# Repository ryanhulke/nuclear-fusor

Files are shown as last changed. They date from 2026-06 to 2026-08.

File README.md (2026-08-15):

# Nuclear Fusor
A [nuclear fusor](https://en.wikipedia.org/wiki/Fusor) is an inertial electrostatic confinement device that uses a strong electric field to ionize deuterium gas and accelerate the ions toward the center of a vacuum chamber. This is accomplished by applying a large negative voltage to an inner metal grid (the cathode) relative to the grounded chamber wall (the anode). The chamber is operated at low pressure so that ions can travel significant distances and gain energy from the electric field before colliding with other particles. Near the center of the device, some ions collide with enough kinetic energy that, although they still cannot classically overcome the strong [Coulomb repulsion force](https://en.wikipedia.org/wiki/Coulomb's_law) between their positively charged nuclei, they can occasionally [tunnel](https://en.wikipedia.org/wiki/Quantum_tunnelling) through the Coulomb barrier and may fuse, releasing energy and producing fusion products such as neutrons. These devices are purely experimental; they are highly energy-inefficient and have no commercial future. If you have to ask, "then why would I build one?", you probably shouldn't.

## Project Description
Hardware, firmware, and desktop software for the fusor. The build employs 3 microcontrollers with Bluetooth Low-Energy (BLE). One interfaces with the pressure gauge and streams pressure readings to the control panel, another monitors the high-voltage and current, and the third actuates the gas metering valve for remote pressure control. The desktop app control panel brings the live readouts and valve controls together, with option to stream your phone camera to your computer so you can view the plasma at a safe distance. You can also replay recorded sensor logs and camera footage in the control panel for post-run analysis, in either standard or mobile view.

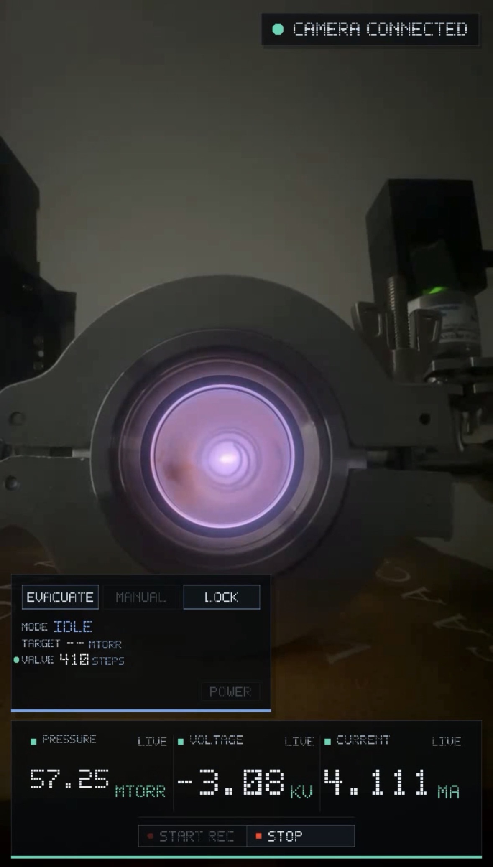
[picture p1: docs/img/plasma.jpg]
Control Panel: Mobile View


## Core Components
- a vacuum pump
  - https://www.amazon.com/Kozyvacu-Dual-Stage-HVAC-Vacuum-Pump/dp/B01N0SYCL4/ref=sr_1_1?sr=8-1
- a vacuum chamber with a view port
  - source these parts from ebay. Use KF or Conflat fittings.
- a high-voltage feedthrough into the chamber
- an inner grid connected to the feedthrough (ex. protein shaker ball)
- a variable power supply capable of at least -20kV at a few mA
- deuterium gas source (or just air for testing)
- MKS 901P pressure gauge
- pressure gauge readout board ([pressure-gauge-readout\hardware](pressure-gauge-readout/hardware))
-  remote-controlled valve ([valve-control/Parts.md](valve-control/Parts.md))
- ammeter/voltmeter readout board ([meter-readouts\hardware](meter-readouts/hardware))
- NEMA 17 Stepper motor (mounted to a needle valve on the deuterium inlet side) and driver
- (optional) ESP32-C6 microcontroller to control the motor
  - a more efficient design would be to incorporate valve control into the meter readout board's PCB

## Repository Layout

| Path | Purpose |
| --- | --- |
| `control-panel/` | Windows OpenGL control panel for pressure, meter, valve control, sensor logging, camera background, and playback. |
| `meter-readouts/` | ESP32-C6 firmware and KiCad hardware for the high-voltage/current readout board. |
| `pressure-gauge-readout/` | ESP32-S3 firmware, desktop utilities, and KiCad hardware for the MKS 901P pressure gauge BLE bridge. |
| `valve-control/` | ESP32-C6 firmware for the stepper-driven valve controller. |
| `docs/` | Project notes and supporting documentation. |

Generated build outputs, local logs, camera media, reference papers, IDE state, and local tool installs are intentionally ignored.

## Getting Started
First, check out the hardware and parts lists to make sure you have what you need. Then, set up the software toolchain(s) for the components you want to build.

| What | Toolchain | Where to start |
| --- | --- | --- |
| **Control panel** — the Windows desktop app | CMake + Visual Studio C++ build tools + OpenCV | [control-panel/README.md](control-panel/README.md) |
| **Firmware** — the three microcontroller boards | PlatformIO | [Firmware](#firmware) below |

Everything below assumes **PowerShell, run from the repo root**. Both toolchains need:

- Windows 10 or newer
- Git (`git --version` to confirm)

### Control Panel

The control panel is a native OpenGL desktop app for the live readouts, valve control, camera, sensor logging, and playback. Its setup has a few steps that are easy to get wrong (installing the C++ build tools, pointing CMake at OpenCV, and adding OpenCV's DLLs to `PATH` before running), so it is documented in one place rather than split across files:

**Follow [control-panel/README.md](control-panel/README.md) top to bottom.** It takes you through installing the build tools, installing OpenCV, building, and running, in order.

### Firmware

The firmware runs on three Seeed XIAO microcontrollers that talk to the control panel over BLE.

**1. Install the toolchain**

- **Python 3** — install from https://www.python.org/ with "Add Python to PATH" checked.
- **PlatformIO Core** — install with pip, then confirm it is on `PATH`:
  ```powershell
  pip install platformio
  pio --version
  ```
- **USB drivers for the Seeed XIAO boards** — usually automatic on Windows 10+. Install a driver manually only if a plugged-in board never shows up.

**2. Build and flash each board**

Each board is built from its own directory. The three commands are the same every time: `pio run` compiles, `pio run -t upload` flashes the board over USB, and `pio device monitor` opens the serial console.

```powershell
cd meter-readouts\firmware
pio run
pio run -t upload
pio device monitor

cd ..\..\pressure-gauge-readout\firmware
pio run
pio run -t upload
pio device monitor

cd ..\..\valve-control\firmware
pio run
pio run -t upload
pio device monitor
```

**3. Reference**

Per-board behavior and BLE payloads are documented in:

- [meter-readouts/firmware/README.md](meter-readouts/firmware/README.md)
- [pressure-gauge-readout/README.md](pressure-gauge-readout/README.md) and [pressure-gauge-readout/firmware/README.md](pressure-gauge-readout/firmware/README.md)
- [valve-control/firmware/README.md](valve-control/firmware/README.md)

## BLE Devices

| Device | BLE name | Role |
| --- | --- | --- |
| Meter readout | `Fusor-Meter` | Publishes filtered high-voltage/current readings as `kv=<n>,ma=<n>,sat=<bits>`. |
| Pressure gauge | `PG-XIAO` | Publishes the MKS 901P pressure readout as text. |
| Valve control | `Fusor-Valve` | Publishes `pos=<n>,open=<n>,mode=<mode>` and accepts movement commands. |

The control panel discovers these devices automatically by BLE name/service UUID.

## Hardware

KiCad projects are included for the readout boards:

- `meter-readouts/hardware/MeterReadouts.kicad_pro`
- `pressure-gauge-readout/hardware/readoutPCB.kicad_pro`

## License
MIT.

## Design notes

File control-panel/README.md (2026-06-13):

# Fusor Control Panel

Native OpenGL control panel for the fusor viewport, pressure gauge, meter readouts, valve control, sensor logging, camera background, and playback.

This guide takes you from nothing to a running app in five steps. Run every command in **PowerShell from the repo root**. You install the build tools once (steps 1–3), build once (step 4), and from then on you only repeat step 5 to run.

> **The OpenCV root.** Everything OpenCV-related is derived from one folder — the directory you extract OpenCV into. This guide calls it `$OpenCVRoot`. Set it once and the build and run steps reuse it, so you never hand-type the long paths twice.

## Step 1 — Visual Studio 2022 Build Tools (C++ compiler)

This provides the MSVC C++ compiler that CMake uses to build the app. Without it, the build fails with "no compiler found."

1. Download the **Build Tools for Visual Studio 2022** from https://visualstudio.microsoft.com/downloads/ (scroll to "Tools for Visual Studio").
2. Run the installer and check the **Desktop development with C++** workload, then install.
3. If you already have Visual Studio Community/Professional with the C++ workload, you can skip this.

## Step 2 — CMake 3.21 or newer

1. Install from https://cmake.org/download/ (choose "Add CMake to the system PATH" during install).
2. Confirm it is available:
   ```powershell
   cmake --version
   ```

## Step 3 — OpenCV

The control panel links against OpenCV at build time and loads its DLLs at run time. CMake does **not** download OpenCV for you, so install it yourself.

1. Download the prebuilt Windows package (`opencv-4.x.x-windows.exe`) from https://github.com/opencv/opencv/releases/latest.
2. Run it — it is a self-extractor — and extract to a folder you will remember, for example `C:\Libraries\opencv`. **That folder is your `$OpenCVRoot`.**
3. Confirm the extract produced an `OpenCVConfig.cmake` and a `bin` folder under it:
   ```powershell
   $OpenCVRoot = "C:\Libraries\opencv"   # the folder you extracted into
   Get-ChildItem $OpenCVRoot -Recurse -Filter OpenCVConfig.cmake | Select-Object FullName
   Get-ChildItem $OpenCVRoot -Recurse -Filter opencv_world*.dll | Select-Object FullName
   ```
   For the prebuilt package these resolve to `$OpenCVRoot\build` (the config) and `$OpenCVRoot\build\x64\vc16\bin` (the DLLs). If you built OpenCV from source instead, point `$OpenCVRoot` at your install folder; the two subpaths may differ (e.g. `...\x64\vc16\lib` and `...\x64\vc16\bin`) — use whatever the commands above print.

## Step 4 — Build the app

This compiles the control panel once. You only repeat it after changing the source.

```powershell
$OpenCVRoot = "C:\Libraries\opencv"   # same folder as step 3
cmake -S control-panel -B control-panel\build -DOpenCV_DIR="$OpenCVRoot\build"
cmake --build control-panel\build --config Release
```

The first configure also downloads GLFW and SimpleBLE via CMake `FetchContent`, so it needs internet access. GLAD is vendored in `tools/glad`.

To start clean, delete the build folder and re-run the two commands above:

```powershell
Remove-Item control-panel\build -Recurse -Force
```

## Step 5 — Run the app

⚠️ **Before launching, add OpenCV's DLL folder to your PATH for this PowerShell session.** This is the step people miss: without it Windows cannot find the OpenCV DLLs and the app fails to start with a missing-DLL error. You must redo this in every new PowerShell window.

```powershell
$OpenCVRoot = "C:\Libraries\opencv"   # same folder as step 3
$env:PATH = "$OpenCVRoot\build\x64\vc16\bin;$env:PATH"
& "control-panel\build\Release\Fusor Control Panel.exe"
```

The app scans for the pressure sensor, meter readout, and valve control boards automatically. If it still reports missing DLLs, you ran the `.exe` in a different PowerShell window than the `$env:PATH` line — run both in the same window.

## Setup at a glance

After the one-time tool installs (steps 1–3), the full build-and-run sequence is:

```powershell
$OpenCVRoot = "C:\Libraries\opencv"   # adjust to where you extracted OpenCV

# Build (repeat only after source changes)
cmake -S control-panel -B control-panel\build -DOpenCV_DIR="$OpenCVRoot\build"
cmake --build control-panel\build --config Release

# Run (repeat every new PowerShell session)
$env:PATH = "$OpenCVRoot\build\x64\vc16\bin;$env:PATH"
& "control-panel\build\Release\Fusor Control Panel.exe"
```

## Configure Camera URL

The control panel reads the camera URL from:

```text
control-panel/config/config.yaml
```

Default local bridge config:

```yaml
camera_url: "rtsp://127.0.0.1:8554/fusor"
```

This URL is the MediaMTX RTSP readout on the laptop. The phone streams to MediaMTX separately.

Command-line `--camera-url` still works as a temporary override:

```powershell
& "control-panel\build\Release\Fusor Control Panel.exe" --camera-url "rtsp://127.0.0.1:8554/fusor"
```

## Local iPhone Camera Setup

If you have a Mac, you can obviously use that instead of the iPhone + MediaMTX setup. But for Windows users, the following setup is recommended.

```text
iPhone Moblin -> SRT over iPhone hotspot -> laptop MediaMTX -> RTSP 127.0.0.1 -> Fusor Control Panel
```

The phone and laptop do not need a router. The laptop connects directly to the iPhone hotspot.

### 1. Start The iPhone Hotspot

On iPhone:

```text
Settings -> Personal Hotspot -> Allow Others to Join
```

Connect the laptop to that hotspot.

Find the laptop's hotspot IP:

```powershell
ipconfig
```

Look under the `Wi-Fi` adapter.

Use the laptop's actual IPv4 address in the Moblin URL.

### 2. Install And Run MediaMTX

Download MediaMTX from:

- https://github.com/bluenviron/mediamtx/releases/latest

Download the Windows amd64 zip, extract it, then run:

```powershell
.\mediamtx.exe
```

Allow it through Windows Firewall on private networks.

Default MediaMTX ports:

```text
SRT ingest: 8890/udp
RTSP read: 8554/tcp
```

Leave the MediaMTX PowerShell window open.

### 3. Configure Moblin

Install Moblin on iPhone:

- https://apps.apple.com/us/app/moblin/id6466745933
- https://github.com/eerimoq/moblin

Create a custom stream:

```text
Protocol: SRT
URL: srt://<LAPTOP_HOTSPOT_IP>:8890
Stream ID: publish:fusor
```

Recommended video settings:

```text
Codec: H.264 / AVC
Resolution: 1280x720
FPS: 30
Bitrate: 2000-3000 kbps
Keyframe interval: 1 second
```

### 4. Run With Camera

With MediaMTX running and Moblin streaming, launch the app exactly as in step 5 (the camera is picked up automatically from `config.yaml`):

```powershell
$OpenCVRoot = "C:\Libraries\opencv"   # same folder as setup
$env:PATH = "$OpenCVRoot\build\x64\vc16\bin;$env:PATH"
& "control-panel\build\Release\Fusor Control Panel.exe"
```

## Controls

```text
Left drag: orbit 3D view
Mouse wheel: zoom 3D view
F: toggle slow 3D rotation
R: start/stop sensor logging
V: show/hide camera background
A/D: jog valve closed/open in manual mode
Esc: quit
```

The valve panel provides `EVACUATE`, `MANUAL`, and `VENT`. `VENT` opens the valve to its reported open limit and is blocked while the meter reports power present.

When the camera is live and visible, the 3D fusor diagram is hidden. If the camera is turned off with `V`, disconnected, or stale, the 3D diagram is shown.

## Sensor Logging

Logging is available when at least one sensor board is connected. Logs are written to:

```text
logs/run_N.log
```

Camera recordings for the same run are written beside the log:

```text
logs/run_N.mp4
logs/run_N.video.tsv
```

The `.video.tsv` file maps video frames to the sensor-log timeline.

Common columns:

```text
elapsed_s    torr    kv    ma    mode    valve_delta    valve_steps    predicted_mtorr    slope_mtorr_s    command_reason    power_present    video_frame_id    video_frames
```

Inactive sensors are logged as empty fields.

## Playback

The playback tool replays a recorded run video with the same control panel HUD over the camera feed:

```powershell
& "control-panel\build\Release\Fusor Playback.exe" 7
```

You can also pass the log path directly:

```powershell
& "control-panel\build\Release\Fusor Playback.exe" "logs\run_7.log" --speed 0.5
```

To hide the valve/control HUD panel during playback:

```powershell
& "control-panel\build\Release\Fusor Playback.exe" 10 --hide-valve-control
```

To rotate playback video 90 degrees clockwise for a vertical view while keeping
the HUD at the bottom of that rotated view:

```powershell
& "control-panel\build\Release\Fusor Playback.exe" 10 --vertical
```

If a vertical run appears upside down, flip the final oriented frame:

```powershell
& "control-panel\build\Release\Fusor Playback.exe" 10 --vertical --flip
```

To export the video with the HUD overlay instead of opening the playback window:

```powershell
& "control-panel\build\Release\Fusor Playback.exe" 10 --vertical --save
```

By default this writes beside the source video using a name like
`run_10_overlay_vertical.mp4`. You can choose the output path and format by
passing a path after `--save`:

```powershell
& "control-panel\build\Release\Fusor Playback.exe" 10 --vertical --flip --save "logs\run_10_overlay_vertical_flip.mp4"
```

Playback keys:

```text
Space: pause/resume
q or Esc: quit
```

## Troubleshooting

- If the phone stream is live but the app does not show video, check the MediaMTX window for a publisher on path `fusor`.
- If the app logs `camera live`, the RTSP path is working.
- The control panel forces OpenCV/FFmpeg to read RTSP over TCP and ignore audio tracks; leaving Moblin audio off is still preferred.
- The phone will not appear in BLE scan output. BLE scanning is only for the pressure and meter boards.
- If console output mentions `hevc`, switch Moblin to H.264/AVC.
- If Moblin cannot connect, check the laptop Wi-Fi IPv4 address and Windows Firewall.
- If delay is high, lower resolution/bitrate, use H.264, turn audio off, and reduce SRT latency.

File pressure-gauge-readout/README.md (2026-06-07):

# Pressure Gauge Readout

BLE bridge, desktop utilities, and hardware files for reading an MKS 901P
pressure transducer from the control panel app.

## Layout

| Path | Purpose |
| --- | --- |
| `firmware/` | PlatformIO firmware for the Seeed XIAO ESP32S3 BLE pressure bridge. |
| `desktop/server.py` | Simple BLE smoke-test listener for the production pressure payload. |
| `desktop/calibrate_901p.py` | Maintenance script for 901P command/calibration workflows. |
| `hardware/` | KiCad PCB project and mechanical files. |
| `docs/901P-Loadlock-Transducer-Manual.pdf` | Local copy of the 901P transducer manual. |

## Firmware

The firmware uses PlatformIO. If PlatformIO is not installed yet:

```powershell
python -m pip install --upgrade platformio
pio --version
```

Build and upload from the firmware directory:

```powershell
cd pressure-gauge-readout\firmware
pio run
pio run -t upload
```

The production firmware advertises as `PG-XIAO`, queries `@253PR4?;FF`, and
publishes the parsed pressure string over BLE. See `firmware/README.md` for the
full BLE UUIDs and payload format.

## BLE Smoke Test

Use `desktop/server.py` when you only need to verify that the board advertises,
connects, and publishes pressure notifications.

Install the Python dependency for the desktop scripts:

```powershell
python -m pip install bleak
```

Run from the repo root:

```powershell
python pressure-gauge-readout\desktop\server.py
```

The script prints each BLE notification as raw text. It is intentionally small
and does not depend on the control panel app.

## Calibration Utility

`desktop/calibrate_901p.py` is kept as a maintenance utility for direct 901P
command/calibration workflows. It is not required for normal control panel operation.

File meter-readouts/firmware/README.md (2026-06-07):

# Meter Readouts Firmware

Firmware for the Fusor meter readout board. The board reads high-voltage and
current sense signals through an ADS1115 and publishes filtered production
readings over USB serial and BLE.

## Requirements

- Python 3
- PlatformIO Core
- Seeed XIAO ESP32-C6
- ADS1115 on I2C address `0x48`

Verify PlatformIO:

```powershell
python -m pip install --upgrade platformio
pio --version
```

## Build And Upload

From this directory, build first:

```powershell
pio run
```

Connect the XIAO over USB, then upload:

```powershell
pio run -t upload
```

Open the serial monitor:

```powershell
pio device monitor
```

Serial monitor speed is `115200`.

PlatformIO reads the board, framework, upload speed, serial speed, and library
dependencies from `platformio.ini`. The first build downloads the ESP32 platform
and libraries, so it needs internet access.

## Initialization

On boot the firmware:

1. Starts USB serial and prints `Starting Fusor Meter`.
2. Initializes I2C on the board's default `SDA` and `SCL` pins at 100 kHz.
3. Looks for the ADS1115 at `0x48`.
4. Configures the ADS1115 for `GAIN_SIXTEEN` and `128 SPS`.
5. Starts BLE advertising as `Fusor-Meter`.

If the ADS1115 is not found, the board still advertises over BLE but reports:

```text
ERR ADS1115
```

It retries ADS1115 initialization every 3 seconds and reports
`INFO ADS1115 ready` after recovery.

Boot-time input zeroing is disabled by default. To enable it, set
`autoZeroAtBoot` to `true` in `src/main.cpp` and boot with both inputs held at
their zero condition.

## Operation

Every 250 ms the firmware reads:

- ADS1115 differential channel `0-1` for the high-voltage divider sense input.
- ADS1115 differential channel `2-3` for the current shunt sense input.

The readings are averaged, converted to `kV` and `mA`, filtered, printed to USB
serial, and sent over the BLE data characteristic when a client is connected.

BLE details:

```text
Device name: Fusor-Meter
Service UUID: 9b3f1001-7f64-4f76-8f6d-8a2f0b6a4c10
Data UUID:    9b3f1002-7f64-4f76-8f6d-8a2f0b6a4c10
```

Payload format:

```text
kv=<filtered kV>,ma=<total mA>,sat=<voltage saturated><current saturated>
```

`sat=10` means the voltage ADC input is saturated and the current ADC input is
not.

Calibration constants are near the top of `src/main.cpp`:

```text
hvResistorOhms
voltageSenseOhms
currentShuntOhms
voltageSign
currentSign
```

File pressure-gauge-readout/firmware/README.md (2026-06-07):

# Pressure Gauge Readout Firmware

Firmware for the MKS 901P pressure gauge BLE bridge. The board reads the gauge
over UART and publishes the current pressure value over BLE for the control panel app
and simple diagnostic tools.

## Requirements

- Python 3
- PlatformIO Core
- Seeed XIAO ESP32S3
- MKS 901P pressure transducer connected to the XIAO hardware UART
- BLE-capable host for the control panel or desktop test scripts

Verify PlatformIO:

```powershell
python -m pip install --upgrade platformio
pio --version
```

## Build And Upload

From this directory, build first:

```powershell
pio run
```

Connect the XIAO over USB, then upload:

```powershell
pio run -t upload
```

Open the serial monitor:

```powershell
pio device monitor
```

Serial monitor speed is `115200`.

PlatformIO reads the board, framework, serial speed, and library dependencies
from `platformio.ini`. The first build downloads the ESP32 platform and
libraries, so it needs internet access.

## Wiring

The firmware uses the XIAO board's labeled serial pins:

| XIAO pin | Connects to |
| --- | --- |
| `RX` / GPIO44 | 901P TX |
| `TX` / GPIO43 | 901P RX |

The 901P serial link is configured for `9600` baud.

## Operation

On boot the firmware:

1. Starts USB serial.
2. Opens the 901P UART.
3. Starts BLE advertising as `PG-XIAO`.
4. Queries the 901P every 200 ms with `@253PR4?;FF`.
5. Publishes the parsed pressure value over BLE.

BLE details:

```text
Device name: PG-XIAO
Service UUID: 9b3f0001-7f64-4f76-8f6d-8a2f0b6a4c10
Data UUID:    9b3f0002-7f64-4f76-8f6d-8a2f0b6a4c10
```

Normal payload format:

```text
<pressure> Torr
```

Error payloads:

```text
ERR parse
ERR timeout
```

`ERR parse` means the gauge returned data that did not match the expected 901P
ACK format. `ERR timeout` means no complete `;FF`-terminated response arrived
before the read timeout.

## Desktop BLE Test Script

`pressure-gauge-readout/desktop/server.py` is a lightweight BLE smoke test. It
scans for the pressure gauge bridge, connects, subscribes to notifications, and
prints raw payloads.

Install the Python dependency:

```powershell
python -m pip install bleak
```

Run it from the repo root:

```powershell
python pressure-gauge-readout\desktop\server.py
```

This script is useful for checking BLE advertisement, connection, and payload
format without launching the full control panel.

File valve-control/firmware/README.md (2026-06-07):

# Fusor Valve Stepper Controller

Firmware for digitally controlling the fusor gas metering valve with a Seeed XIAO ESP32-C6, TB6600 stepper driver, and NEMA 17 stepper motor.

The controller tracks valve position in step counts, saves position and calibration values to flash, exposes BLE control for the control panel app, and keeps a USB serial console available for calibration and maintenance.

## Hardware

- Seeed XIAO ESP32-C6
- TB6600 stepper motor driver
- NEMA 17 stepper motor
- 12 V DC power supply, 3-5 A recommended
- Metering valve with motor/coupler mount

Stepper settings:

- Microstepping: 16 microsteps
- Steps per revolution: 3200
- TB6600 current limit: 2 A

## Software Requirements

- Python 3
- PlatformIO Core

Verify PlatformIO:

```powershell
pip install platformio
pio --version
```

PlatformIO reads the board, framework, upload speed, serial speed, partition
layout, and library dependencies from `platformio.ini`. The first build
downloads the ESP32 platform and libraries, so it needs internet access.

## Build, Upload, And Serial

From this directory, build first:

```powershell
pio run
```

Connect the XIAO over USB, then upload:

```powershell
pio run -t upload
```

Open the USB serial console:

```powershell
pio device monitor
```

Serial monitor speed is `115200`.

The serial console is not only for first-time setup. It remains available during normal operation. If the control panel is connected over BLE, you can still plug in USB, open the PlatformIO serial monitor, jog the valve, print status, restore limits, or recalibrate.

## Normal Operation

In normal operation:

1. Power the valve controller.
2. Start the control panel app.
3. The control panel connects over BLE to `Fusor-Valve`.
4. The firmware reports status once per second and after every move.
5. The control panel sends text commands over BLE, such as `MOVETO`, `MOVE`, `CLOSE`, and `OPEN`.

The firmware also accepts the same text commands from USB serial. On USB, type `:` first, then the command, then Enter.

Example:

```text
:STATUS
:MOVETO 1200
:CLOSE
```

## RUN vs CALIBRATE

The firmware has two persisted modes:

- `RUN`: normal clamped operation. Absolute and relative moves are clamped to `[0, openLimitSteps]`.
- `CALIBRATE`: unclamped operation. Use this when finding or correcting the physical closed and open references.

Switch modes from USB serial or BLE:

```text
:MODE RUN
:MODE CALIBRATE
```

Calibration is not a separate firmware or special boot mode. It is always available through USB serial. For normal control-panel-driven use, leave the controller in `RUN`. When you need to recalibrate, connect USB, open `pio device monitor`, switch to `CALIBRATE`, make corrections, then switch back to `RUN`.

Position is saved after every completed move in both modes. The open limit and mode are also saved when changed.

## First-Time Calibration

Use USB serial for calibration.

1. Upload the firmware and open `pio device monitor`.
2. Switch to calibration mode:

   ```text
   :MODE CALIBRATE
   ```

3. Start the vacuum pump.
4. Jog toward closed with `a` or the left arrow while watching pressure.
5. When pressure stops dropping, treat that as the closed reference and press `z`.
6. Jog toward open with `d` or the right arrow.
7. When the valve is open far enough for your system, press `m` to save the open limit.
8. Press `p` or type `:STATUS` and confirm `pos`, `open`, and `mode`.
9. Switch back to clamped normal operation:

   ```text
   :MODE RUN
   ```

After this, the control panel can use the reported `open=<n>` value for Vent and manual jogs remain clamped inside the saved range.

## Recalibration During Normal Use

You can recalibrate without reflashing and without changing how the control panel connects.

1. Leave the controller powered.
2. Connect USB.
3. Open:

   ```text
   pio device monitor
   ```

4. Switch to `CALIBRATE` if you need unclamped jogs:

   ```text
   :MODE CALIBRATE
   ```

5. Correct the position or limit:

   ```text
   :SETPOS <n>
   :SETOPEN <n>
   ```

   Or jog to the references and use `z` / `m`.

6. Switch back to `RUN`:

   ```text
   :MODE RUN
   ```

BLE remains active while doing this. Be careful not to command motion from the control panel and the serial console at the same time.

## Restoring Calibration Without Jogging

If flash was wiped or you already know the calibration values, restore them directly:

```text
:SETOPEN 12800
:SETPOS 7800
:MODE RUN
```

`SETOPEN` requires a positive value. `SETPOS` is clamped if the firmware is currently in `RUN`; switch to `CALIBRATE` first if you need to assert a position outside the current limit.

## USB Serial Commands

Single-character commands execute immediately:

| Key | Effect |
| --- | --- |
| `a` / left arrow | Jog closed |
| `d` / right arrow | Jog open |
| `c` | Move to closed position `0` |
| `o` | Move to the saved open limit |
| `p` | Print status and publish BLE status |
| `z` | Set current position as zero |
| `m` | Mark current position as open limit |
| `[` / `]` | Smaller / bigger jog size |
| `?` | Print help |

Text commands use `:` plus Enter:

```text
:MODE CALIBRATE
:MODE RUN
:SETOPEN <n>
:SETPOS <n>
:MOVETO <n>
:MOVE <delta>
:CLOSE
:OPEN
:STATUS
```

Backspace edits the line buffer. Escape cancels the buffered command.

## BLE Interface

BLE is always active in both `RUN` and `CALIBRATE`.

```text
Device name:    Fusor-Valve
Service UUID:   9b3f2001-7f64-4f76-8f6d-8a2f0b6a4c10
Status UUID:    9b3f2002-7f64-4f76-8f6d-8a2f0b6a4c10  (read + notify)
Command UUID:   9b3f2003-7f64-4f76-8f6d-8a2f0b6a4c10  (write)
```

Status payload:

```text
pos=<n>,open=<n>,mode=<CALIBRATE|RUN>
```

The status characteristic is updated after every move and once per second as a heartbeat.

The command characteristic accepts the text commands listed above without the leading `:`.

Examples:

```text
STATUS
MOVETO 1200
OPEN
CLOSE
MODE RUN
```

## Position Tracking And Limits

The firmware stores:

- current position: `pos`
- open limit: `open`
- mode: `RUN` or `CALIBRATE`

Position is saved after every completed move. With the partition layout pinned in `platformio.ini`, normal firmware uploads preserve NVS, so calibration should survive firmware updates.

Position can still drift from the physical valve if:

- the motor skips steps,
- the coupler slips,
- the valve is turned by hand while the controller is powered off,
- power is lost during a move.

After any of those, reconnect USB and resync with `:SETPOS <n>`, or jog to a known closed reference and press `z`.

## Notes

- In `RUN`, moves are clamped to `[0, openLimitSteps]`.
- In `CALIBRATE`, moves are intentionally unclamped.
- `OPEN` requires `openLimitSteps > 0`; otherwise it leaves the valve in place and republishes status.
- `MOVETO` and `MOVE` are also clamped in `RUN`.
- The stepper driver is enabled automatically while moving.

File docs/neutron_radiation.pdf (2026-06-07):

## Neutron Radiation From IEC Fusion Reactor

Ryan Hulke

May 20, 2026

Assume isotropic emission:
ϕ(r) = Y
4πr²
| Where Y is the neutron emission rate in neutrons/s and r is distance from the source.
| Assume worst conditions:
Y = 1,000,000 neutrons/s, | r = 1 m
| My fusor is far less capable, and I will be farther than 1 m away.
| The neutron flux is:
ϕ =

1,000,000
4π

n
s · m²

Need a conversion factor from neutrons to Sieverts. Sieverts measure health risk from ionizing radiation while accounting for radiation type and tissue weighting.

| Use Table A.41 from ICRP Publication 116, page 199.
| Source: https://journals.sagepub.com/doi/10.1016/S0146-6453%2896%2990010-X

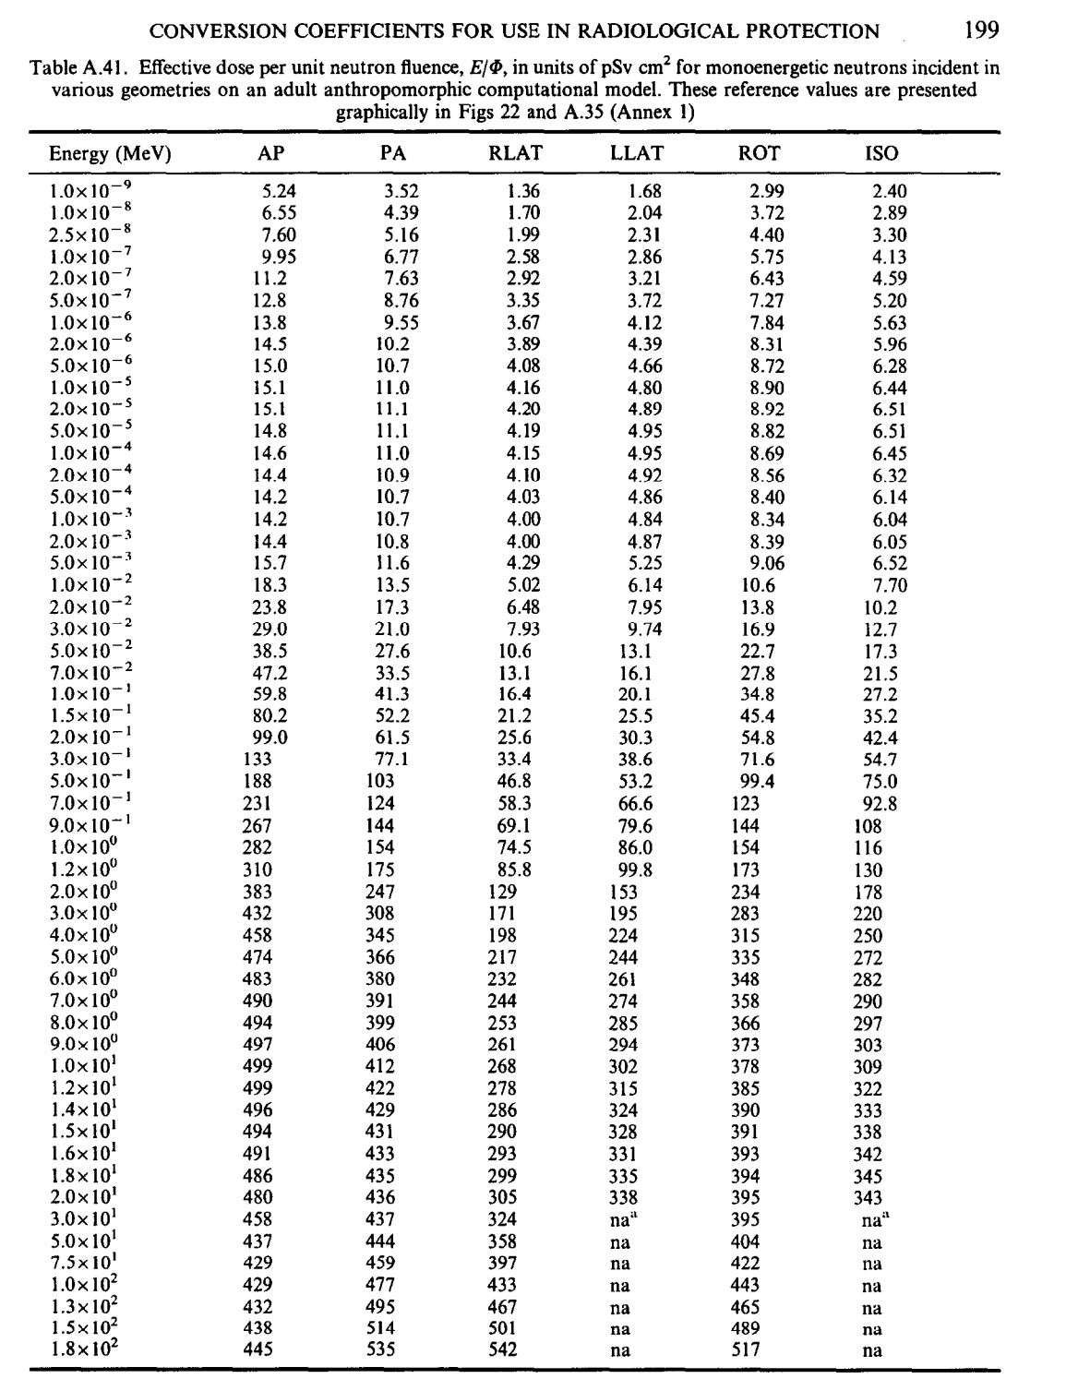
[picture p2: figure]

Effective dose per unit neutron fluence, E/Φ, from ICRP Publication 116 Table A.41.

| The AP column means anterior-to-posterior, which is what you want if a person is facing the radiation source.
| From the table: 2.0 MeV : 383 pSv cm² /neutron 3.0 MeV : 432 pSv cm² /neutron

| D-D fusor neutrons are 2.45 MeV, so interpolate:
| h ≈ 383 + 0.45(432 − 383)
| h ≈ 405 pSv cm² /neutron
| Convert units:
| 405 pSv cm² /neutron = 405 × 10⁻¹² Sv × 10⁻⁴ m² /neutron
| h ≈ 4.05 × 10⁻¹⁴ Sv m² /neutron
| So we use the scaling factor:
| h ≈ 4 × 10⁻¹⁴ Sv m² /neutron
| Plug back in: E˙ ≈ 1,000,000 4π n s · m² · 4 × 10⁻¹⁴ Sv m² n
| Simplify: E˙ ≈ 1,000,000 4π · 4 × 10⁻¹⁴ Sv s E˙ ≈ 3.18 × 10⁻⁹ Sv/s
| E˙ ≈ 3.18 nSv/s
| Scale to hours: E˙ ≈ 3.18 nSv/s · 3600 s/hr
| E˙ ≈ 11.5 µSv/hr
| For context, the NRC public-dose limit for licensed operations is 1 mSv/yr and the unrestricted- area external dose-rate limit is 20 µSv/hr.
| NRC source: https://www.law.cornell.edu/cfr/text/10/20.1301
| Therefore, even a relatively high-yield homemade fusor at 10⁶ neutrons/s gives a neutron dose rate below the NRC unrestricted-area hourly dose-rate limit at 1 m away.
| In fact, natural background radiation is about 0.3 µSv/hr, per the CDC. (https://www.cdc.gov/radiation-health/about/how-to-measure-radiation.html)
| So for every hour you operate a high-powered fusor from 1 m away, you are exposed to about 38 hours of natural background radiation. Nothing.
| This also scales linearly with neutrons/s. So if we assume a more reasonable estimate of 50,000 neutrons/s for my fusor instead of 1,000,000 neutrons/s, exposure drops by a factor of 20: E˙ ≈
| 11.5
| 20 µSv/hr
| E˙ ≈ 0.575 µSv/hr
| when standing 1 m away.

| Distance scales as 1/r² , so going from 1 m to 3 m reduces exposure by a factor of:
| 3 2 = 9
| Therefore: E˙ 3m =
| 0.575
| 9 µSv/hr
| E˙ 3m ≈ 0.064 µSv/hr when standing 3 m away at 50,000 neutrons/s.
| This is the most reasonable estimate for actual operational neutron exposure from my fusor.
| Conclusion: Neutron radiation from my fusor is negligible past 1 m away from the fusor. Just don’t hug it at peak operation.

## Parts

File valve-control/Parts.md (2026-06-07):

# Parts List
- 1x KF16 Vacuum Flow Regulating Valve Metering Controller Needle Valve
- 1x NEMA 17 Stepper Motor
- 1x TB6600 Driver
- 1x XIAO ESP32C6 Microcontroller
- 1x Power Supply (12V/3A)
- 1x 5mm to 6mm Shaft Coupler
- 1x 30mm Inner-width Square U-bolt
- 1x 42mm Stepper Motor Mounting Bracket
- 100x65mm Aluminum Sheet
- 1x Perfboard
- 11x wires
- 1x 3 Double-A Battery Holder
- 3x Double-A Batteries

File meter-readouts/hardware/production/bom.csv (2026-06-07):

Designator | Footprint | Quantity | Value | LCSC Part #
C1, C2, C3, C4 | 0805 | 4 | 100 nF
C5 | 0805 | 1 | 10 uF
D1, D2, D3, D4, D5 | D_SOD-123 | 5 | D_Schottky
R1, R2, R4, R5 | 0805 | 4 | 47 kOhm
R3 | 0805 | 1 | 1 kOhm
R7, R8 | 0805 | 2 | 4.7 kOhm
U1 | TSSOP-10_3x3mm_P0.5mm | 1 | ADS1115IDGS

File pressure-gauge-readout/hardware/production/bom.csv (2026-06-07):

Designator | Footprint | Quantity | Value | LCSC Part #
C1, C10, C11, C12, C4, C6, C8, C9 | 0603 | 8 | 100nF
C2, C3, C5, CR1 | 0603 | 4 | 10uF
D1, D2 | D_SOD-123 | 2 | D_Schottky
F1 | 1812 | 1 | Polyfuse
U1 | SOIC-16_3.9x9.9mm_P1.27mm | 1 | MAX3232

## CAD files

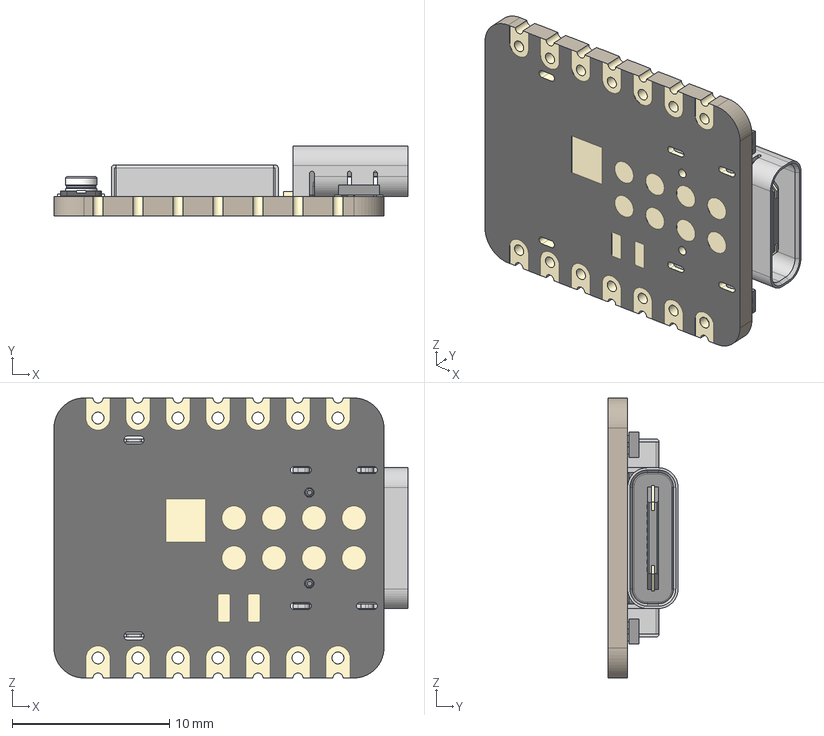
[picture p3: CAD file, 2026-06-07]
meter-readouts/hardware/3dmodels/XIAO-ESP32S3 v2.step
22.5 x 4.46 x 17.8 mm
BOSS-EXTRUDE14_8_
BOSS-EXTRUDE7_4_
BOSS-EXTRUDE7_3_
BOSS-EXTRUDE14_4_
BOSS-EXTRUDE14_2_
BOSS-EXTRUDE14_11_
BOSS-EXTRUDE7_7_
BOSS-EXTRUDE14_9_
BOSS-EXTRUDE14_3_
BOSS-EXTRUDE14_7_
MIRROR2
BOSS-EXTRUDE14_5_
BOSS-EXTRUDE14_12_
BOSS-EXTRUDE7_8_
BOSS-EXTRUDE7_1_
BOSS-EXTRUDE14_10_
BOSS-EXTRUDE7_9_
BOSS-EXTRUDE14_6_
BOSS-EXTRUDE14_1_
BOSS-EXTRUDE7_6_
BOSS-EXTRUDE7_2_
CUT-EXTRUDE5
BOSS-EXTRUDE7_5_
Shield
Pins x 2
U.FL-R-SMT-1_10_ v1

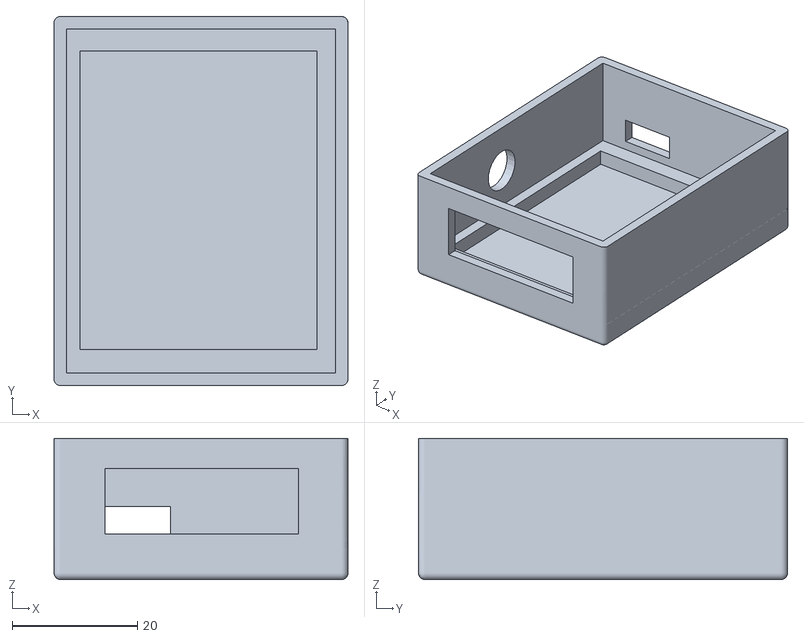
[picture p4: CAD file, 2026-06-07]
pressure-gauge-readout/hardware/3dmodels/enclosure-bottom.stl
46.9 x 58.9 x 22.5

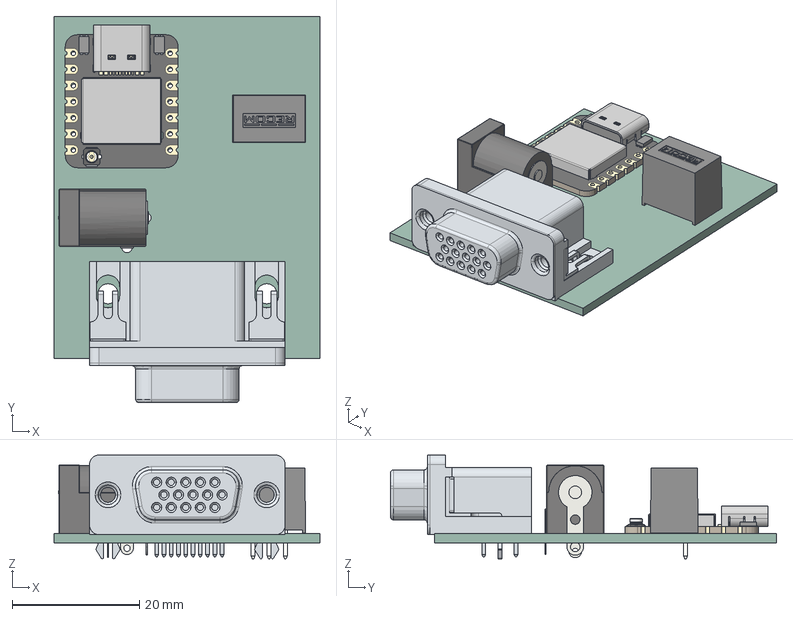
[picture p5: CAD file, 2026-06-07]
pressure-gauge-readout/hardware/readoutPCB.step
41.9 x 60.8 x 16.4 mm
K66X_HT__E15S_N_rA5
BarrelJack_Horizontal
R-78K-1.0_3D_20230223
BOSS-EXTRUDE14_8_
BOSS-EXTRUDE7_4_
BOSS-EXTRUDE7_3_
BOSS-EXTRUDE14_4_
BOSS-EXTRUDE14_2_
BOSS-EXTRUDE14_11_
BOSS-EXTRUDE7_7_
BOSS-EXTRUDE14_9_
BOSS-EXTRUDE14_3_
BOSS-EXTRUDE14_7_
MIRROR2
BOSS-EXTRUDE14_5_
BOSS-EXTRUDE14_12_
BOSS-EXTRUDE7_8_
BOSS-EXTRUDE7_1_
BOSS-EXTRUDE14_10_
BOSS-EXTRUDE7_9_
BOSS-EXTRUDE14_6_
BOSS-EXTRUDE14_1_
BOSS-EXTRUDE7_6_
BOSS-EXTRUDE7_2_
CUT-EXTRUDE5
BOSS-EXTRUDE7_5_
Shield
Pins x 2
U.FL-R-SMT-1_10_ v1
readoutPCB_PCB

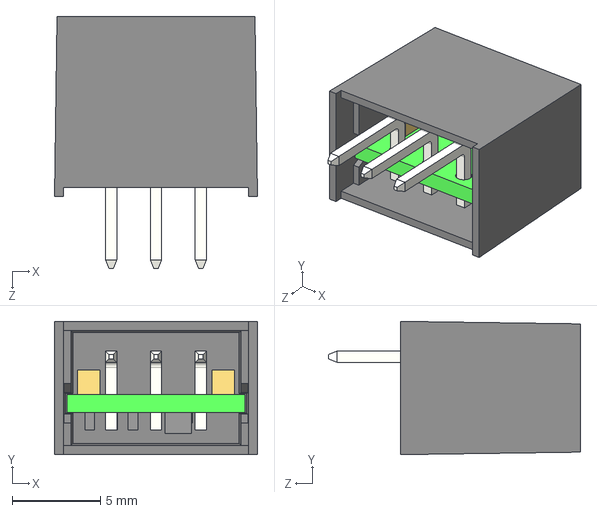
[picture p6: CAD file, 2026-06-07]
pressure-gauge-readout/hardware/3dmodels/R-78K5.0-1.0.step
11.5 x 7.55 x 14.3 mm

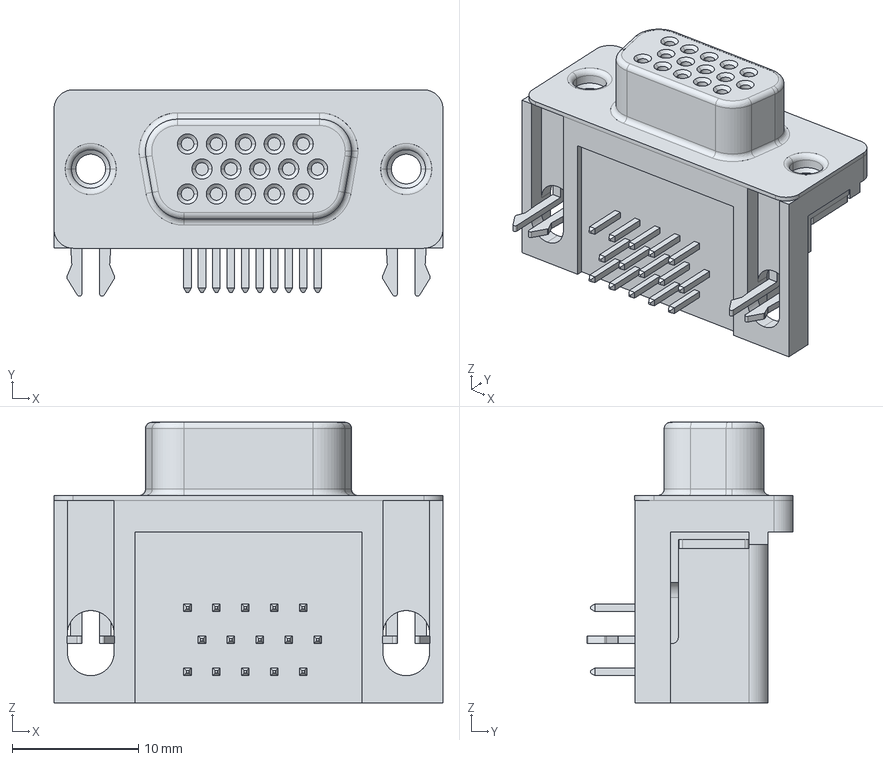
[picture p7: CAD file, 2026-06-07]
pressure-gauge-readout/hardware/3dmodels/female_rightAngle_HD15.step
30.8 x 16.4 x 22.2 mm

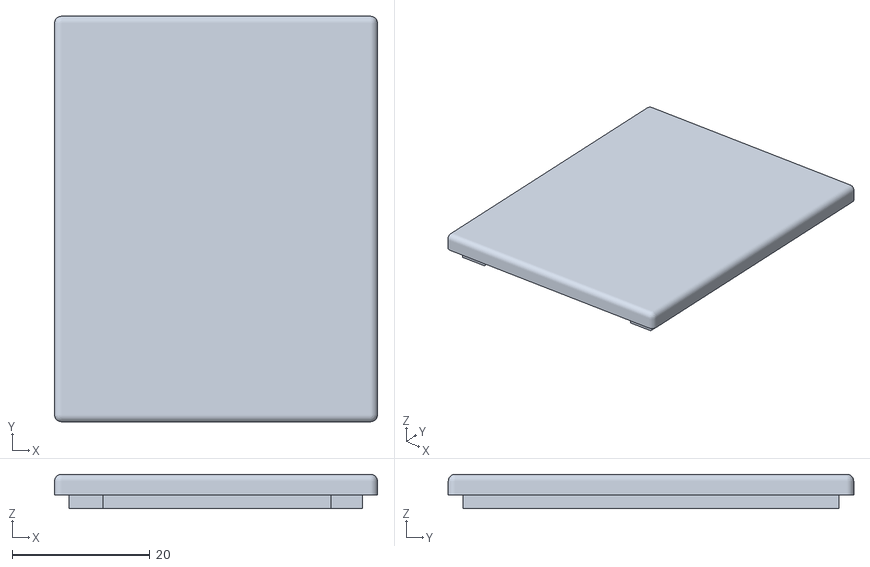
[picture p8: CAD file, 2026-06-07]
pressure-gauge-readout/hardware/3dmodels/enclosure-roof.stl
46.9 x 58.9 x 5.00

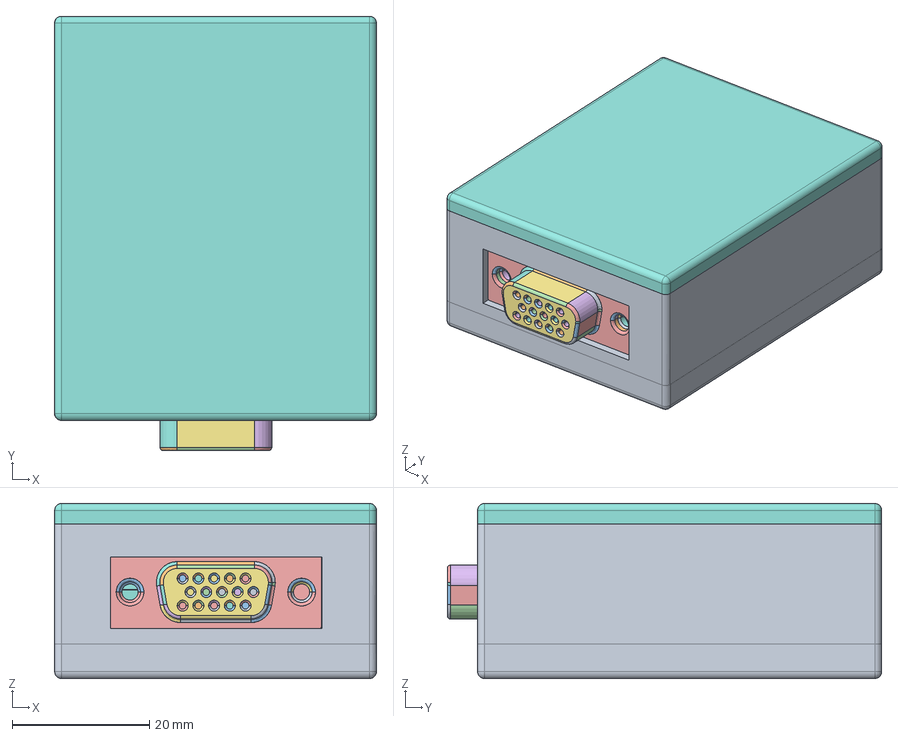
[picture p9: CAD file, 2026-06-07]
pressure-gauge-readout/hardware/3dmodels/enclosure.FCStd
46.9 x 63.3 x 25.5 mm
K66X_HT__E15S_N_rA5
K66X_HT__E15S_N_rA001
K66X_HT__E15S_N_rA002
K66X_HT__E15S_N_rA003
K66X_HT__E15S_N_rA004
K66X_HT__E15S_N_rA005
K66X_HT__E15S_N_rA006
K66X_HT__E15S_N_rA007
K66X_HT__E15S_N_rA008
K66X_HT__E15S_N_rA009
K66X_HT__E15S_N_rA010
K66X_HT__E15S_N_rA011
K66X_HT__E15S_N_rA012
K66X_HT__E15S_N_rA013
K66X_HT__E15S_N_rA014
K66X_HT__E15S_N_rA015
K66X_HT__E15S_N_rA016
K66X_HT__E15S_N_rA017
K66X_HT__E15S_N_rA018
K66X_HT__E15S_N_rA019
K66X_HT__E15S_N_rA020
K66X_HT__E15S_N_rA021
K66X_HT__E15S_N_rA022
K66X_HT__E15S_N_rA023
K66X_HT__E15S_N_rA024
K66X_HT__E15S_N_rA025
K66X_HT__E15S_N_rA026
K66X_HT__E15S_N_rA027
K66X_HT__E15S_N_rA028
K66X_HT__E15S_N_rA029
K66X_HT__E15S_N_rA030
K66X_HT__E15S_N_rA031
K66X_HT__E15S_N_rA032
K66X_HT__E15S_N_rA033
K66X_HT__E15S_N_rA034
K66X_HT__E15S_N_rA035
K66X_HT__E15S_N_rA036
K66X_HT__E15S_N_rA037
K66X_HT__E15S_N_rA038
K66X_HT__E15S_N_rA039
K66X_HT__E15S_N_rA040
K66X_HT__E15S_N_rA041
K66X_HT__E15S_N_rA042
K66X_HT__E15S_N_rA043
K66X_HT__E15S_N_rA044
K66X_HT__E15S_N_rA045
K66X_HT__E15S_N_rA046
K66X_HT__E15S_N_rA047
K66X_HT__E15S_N_rA048
K66X_HT__E15S_N_rA049
K66X_HT__E15S_N_rA050
K66X_HT__E15S_N_rA051
K66X_HT__E15S_N_rA052
K66X_HT__E15S_N_rA053
K66X_HT__E15S_N_rA054
K66X_HT__E15S_N_rA055
K66X_HT__E15S_N_rA056
K66X_HT__E15S_N_rA057
K66X_HT__E15S_N_rA058
K66X_HT__E15S_N_rA059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

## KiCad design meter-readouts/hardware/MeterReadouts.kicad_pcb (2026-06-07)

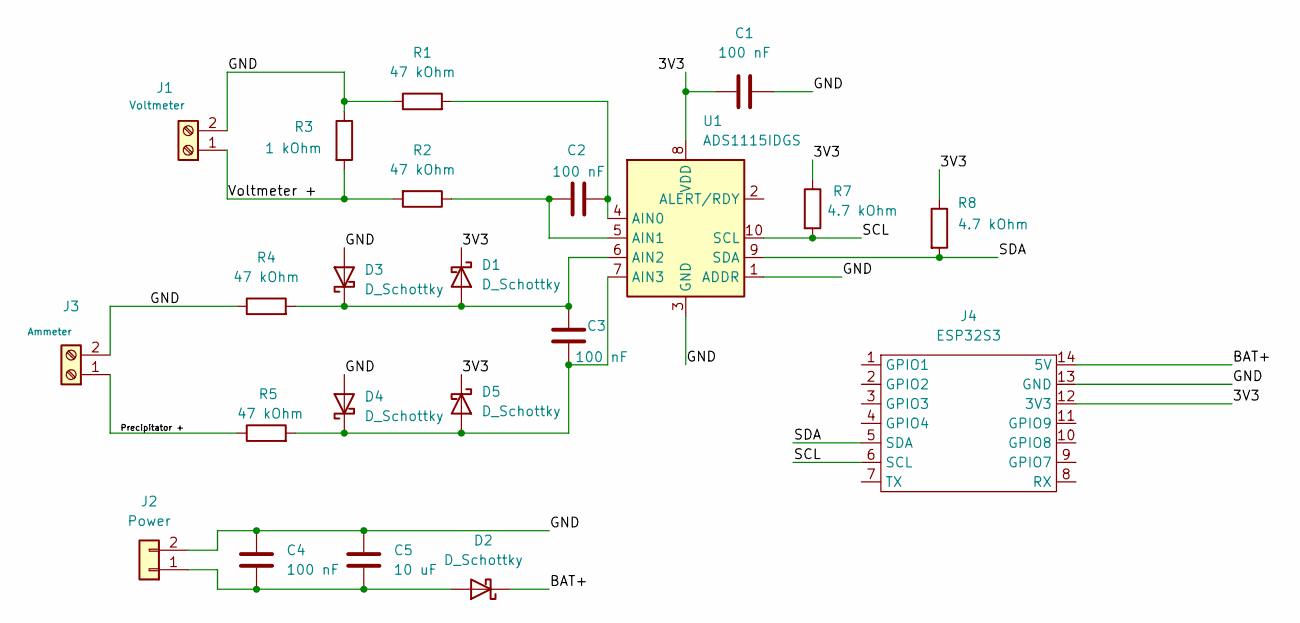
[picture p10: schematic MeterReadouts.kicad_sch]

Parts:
C1, C2, C3, C4: 100 nF; C_0805_2012Metric
C5: 10 uF; C_0805_2012Metric
D1, D2, D3, D4, D5: D_Schottky; D_SOD-123
J1: Voltmeter; TerminalBlock_Phoenix_MKDS-1,5-2-5.08_1x02_P5.08mm_Horizont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
J2: Power; TerminalBlock_Phoenix_MKDS-1,5-2-5.08_1x02_P5.08mm_Horizont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
J3: Ammeter; TerminalBlock_Phoenix_MKDS-1,5-2-5.08_1x02_P5.08mm_Horizont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
J4: ESP32S3; XIAO-ESP32S3-DIP
R1, R2, R4, R5: 47 kOhm; R_0805_2012Metric
R3: 1 kOhm; R_0805_2012Metric
R7, R8: 4.7 kOhm; R_0805_2012Metric
U1: ADS1115IDGS; TSSOP-10_3x3mm_P0.5mm

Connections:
/3V3: C1.1, D1.1 (K), D5.1 (K), J4.12 (3V3), R7.1, R8.1, U1.8 (VDD)
/<NO NET>: J1.1, R2.2, R3.2
/BAT+: D2.1 (K), J4.14 (5V)
/GND: C1.2, C4.2, C5.2, D3.2 (A), D4.2 (A), J1.2, J2.2, J3.2, J4.13 (GND), R1.1, R3.1, R4.1, U1.1 (ADDR), U1.3 (GND)
/Precipitator +: J3.1, R5.1
/SCL: J4.6 (SCL), R7.2, U1.10 (SCL)
/SDA: J4.5 (SDA), R8.2, U1.9 (SDA)
unnamed: C3.2, D1.2 (A), D3.1 (K), R4.2, U1.6 (AIN2)
unnamed: C4.1, C5.1, D2.2 (A), J2.1
unnamed: C3.1, D4.1 (K), D5.2 (A), R5.2, U1.7 (AIN3)
unnamed: C2.2, R1.2, U1.4 (AIN0)
unnamed: C2.1, R2.1, U1.5 (AIN1)

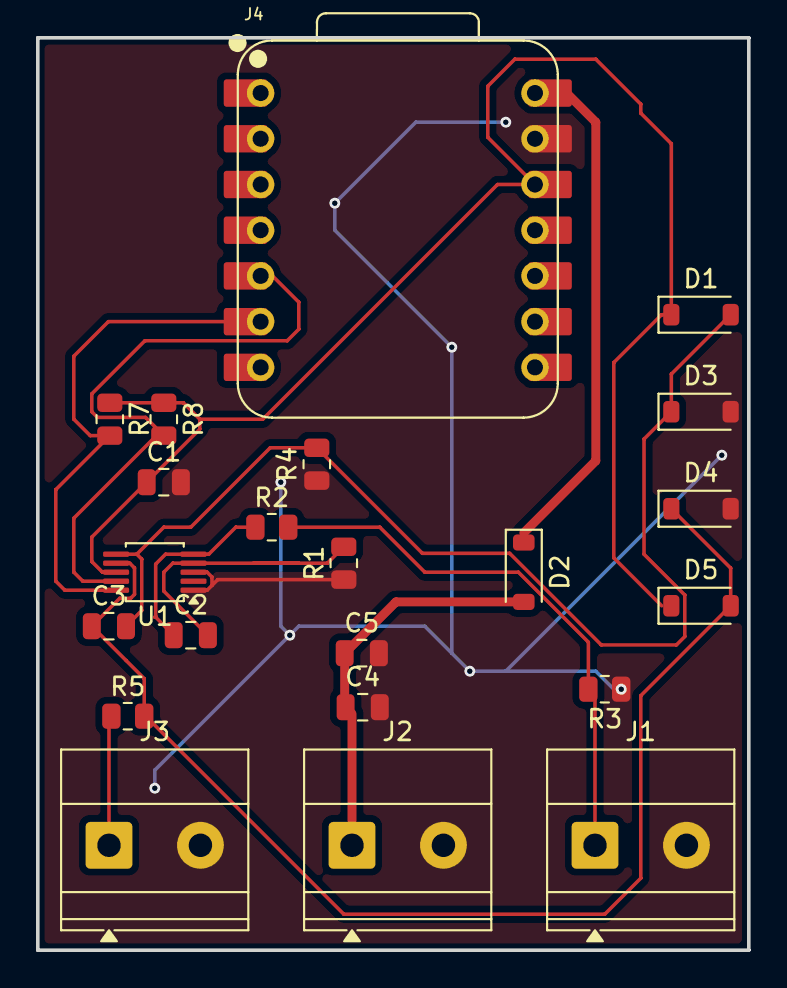
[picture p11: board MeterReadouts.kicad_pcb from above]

Board: 2 copper layers, 39.5 x 50.7 mm, 22 parts (0 on the bottom side), 12 nets.

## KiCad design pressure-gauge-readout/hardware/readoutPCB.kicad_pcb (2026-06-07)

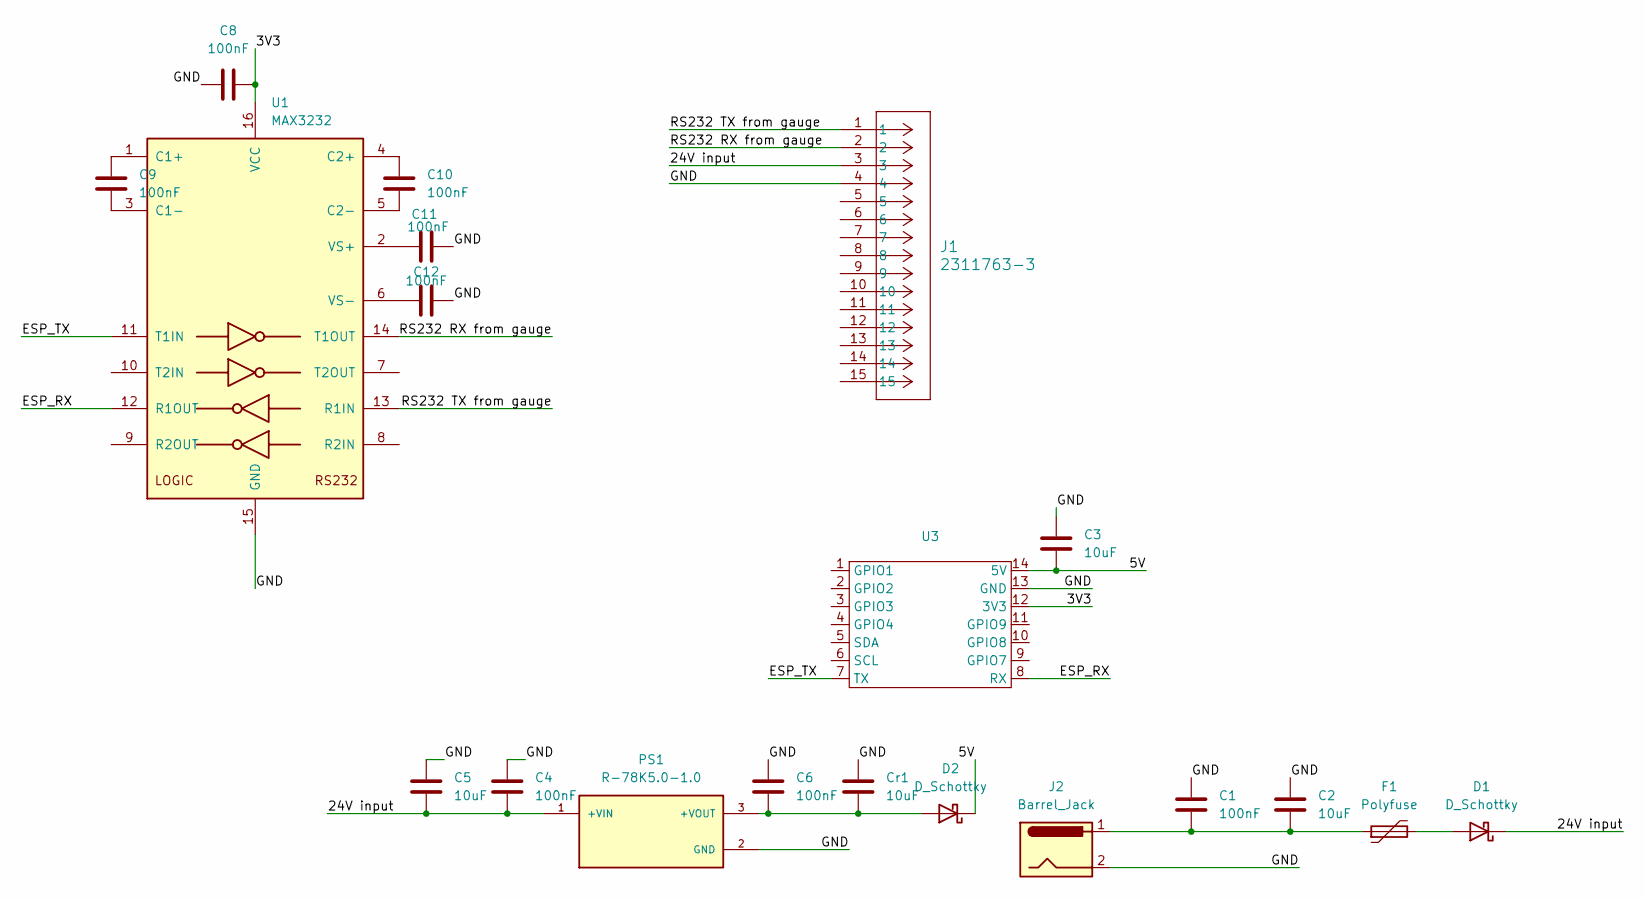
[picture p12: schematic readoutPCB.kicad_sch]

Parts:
C1, C4, C6, C8, C9, C10, C11, C12: 100nF; C_0603_1608Metric
C2, C3, C5: 10uF; C_0603_1608Metric
Cr1: 10uF; C_0603_1608Metric
D1, D2: D_Schottky; D_SOD-123
F1: Polyfuse; Fuse_1812_4532Metric
J1: 2311763-3; CONN_2311763-3_TEC
J2: Barrel_Jack; BarrelJack_CUI_PJ-102AH_Horizontal
PS1: R-78K5.0-1.0; CONV_R-78K5.0-1.0; PARTREV 0/2023
U1: MAX3232; SOIC-16_3.9x9.9mm_P1.27mm
U3: XIAO-ESP32S3-DIP

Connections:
/3V3: C8.2, U1.16 (VCC), U3.12 (3V3)
/5V: C3.2, D2.1 (K), U3.14 (5V)
/24V input: C4.2, C5.2, D1.1 (K), J1.3, PS1.1 (+VIN)
/ESP_RX: U1.12 (R1OUT), U3.8 (RX)
/ESP_TX: U1.11 (T1IN), U3.7 (TX)
/GND: C1.1, C2.1, C3.1, C4.1, C5.1, C6.1, C8.1, C11.2, C12.2, Cr1.1, J1.4, J2.2, PS1.2 (GND), U1.15 (GND), U3.13 (GND)
/RS232 RX from gauge: J1.2, U1.14 (T1OUT)
/RS232 TX from gauge: J1.1, U1.13 (R1IN)
unnamed: C1.2, C2.2, F1.1, J2.1
unnamed: D1.2 (A), F1.2
unnamed: C6.2, Cr1.2, D2.2 (A), PS1.3 (+VOUT)
unnamed: C9.2, U1.1 (C1+)
unnamed: C9.1, U1.3 (C1-)
unnamed: C10.2, U1.4 (C2+)
unnamed: C10.1, U1.5 (C2-)
unnamed: C11.1, U1.2 (VS+)
unnamed: C12.1, U1.6 (VS-)

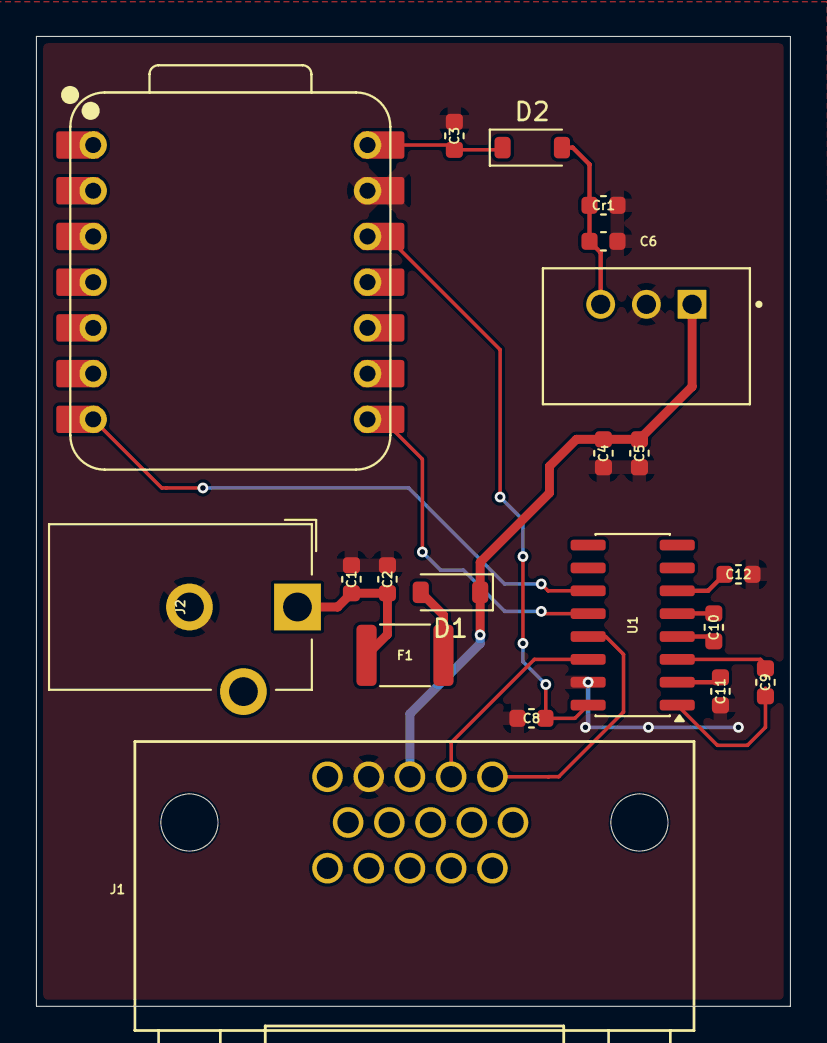
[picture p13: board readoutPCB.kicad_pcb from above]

Board: 2 copper layers, 41.9 x 53.9 mm, 20 parts (0 on the bottom side), 17 nets.

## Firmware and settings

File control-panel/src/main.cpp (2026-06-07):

#include <glad/gl.h>
#include <GLFW/glfw3.h>

#ifdef _WIN32
#define GLFW_EXPOSE_NATIVE_WIN32
#include <windows.h>
#include <dwmapi.h>
#include <GLFW/glfw3native.h>
#include "resource.h"
#endif

#include "Camera/Camera.h"
#include "Control/PressureController.h"
#include "Geometry/Geometry.h"
#include "Math/Math.h"
#include "Meter/MeterMonitor.h"
#include "Plasma/PlasmaRenderer.h"
#include "Pressure/PressureMonitor.h"
#include "Render/Hud.h"
#include "Render/Render.h"
#include "Valve/ValveMonitor.h"
#include "Video/VideoBackground.h"
#include "Video/VideoStream.h"

#include <opencv2/imgproc.hpp>
#include <opencv2/videoio.hpp>

#include <algorithm>
#include <chrono>
#include <cmath>
#include <cctype>
#include <cstdint>
#include <filesystem>
#include <fstream>
#include <iomanip>
#include <iostream>
#include <sstream>
#include <string>
#include <system_error>
#include <thread>
#include <utility>

OrbitCamera gCamera;
bool gAutoRotateCamera = true;
bool gRotationKeyWasDown = false;
bool gRecordingKeyWasDown = false;
bool gVideoKeyWasDown = false;
bool gManualCloseKeyWasDown = false;
bool gManualOpenKeyWasDown = false;
bool gSensorLogControlsEnabled = false;
bool gVideoStreamEnabled = false;
bool gVideoBackgroundVisible = true;
double gLogSavedToastStartedAt = -1000.0;

constexpr float kAutoOrbitRadiansPerSecond = 0.075f;
constexpr long kManualValveStepDelta = 10;
constexpr double kCurrentReportFloorMA = 0.1;
constexpr double kLogSavedToastHoldSeconds = 2.0;
constexpr double kLogSavedToastFadeSeconds = 0.45;
constexpr double kVideoLastFrameHoldSeconds = 2.0;
constexpr double kVideoRecordingFps = 30.0;
constexpr auto kShutdownGracePeriod = std::chrono::milliseconds(2000);

struct SensorLogState {
    bool recording = false;
    std::ofstream stream;
    std::filesystem::path path;
    std::chrono::steady_clock::time_point startedAt{};
    std::chrono::steady_clock::time_point lastLoggedPressureReading{};
    std::chrono::steady_clock::time_point lastLoggedMeterReading{};
    long lastLoggedValveSteps = 0;
    int samplesWritten = 0;
    cv::VideoWriter videoWriter;
    std::ofstream videoIndexStream;
    std::filesystem::path videoPath;
    std::filesystem::path videoIndexPath;
    std::uint64_t lastRecordedVideoFrameId = 0;
    int videoWidth = 0;
    int videoHeight = 0;
    int videoFramesWritten = 0;
    bool videoRecording = false;
    bool videoUnavailable = false;
};

SensorLogState gSensorLog;
SensorHudLayout gSensorHudLayout;
ControlHudLayout gControlHudLayout;
PressureSnapshot gLatestPressure;
MeterSnapshot gLatestMeter;
PressureController gPressureController;
ValveMonitor* gValveMonitor = nullptr;
std::chrono::steady_clock::time_point gLastControlTick{};
bool gControlTicked = false;

enum class PendingValveAction {
    None,
    Evacuate,
    Manual,
    Vent,
};

PendingValveAction gPendingValveAction = PendingValveAction::None;

bool startSensorLogging();
bool stopSensorLogging();
void showLogSavedToast();

#ifdef _WIN32
void applyWindowsWindowIcon(HWND hwnd) {
    const HINSTANCE instance = GetModuleHandleW(nullptr);
    HICON smallIcon = static_cast<HICON>(LoadImageW(
        instance,
        MAKEINTRESOURCEW(IDI_APP_ICON),
        IMAGE_ICON,
        GetSystemMetrics(SM_CXSMICON),
        GetSystemMetrics(SM_CYSMICON),
        LR_DEFAULTCOLOR
    ));
    HICON bigIcon = static_cast<HICON>(LoadImageW(
        instance,
        MAKEINTRESOURCEW(IDI_APP_ICON),
        IMAGE_ICON,
        GetSystemMetrics(SM_CXICON),
        GetSystemMetrics(SM_CYICON),
        LR_DEFAULTCOLOR
    ));

    if (smallIcon) {
        SendMessageW(hwnd, WM_SETICON, ICON_SMALL, reinterpret_cast<LPARAM>(smallIcon));
        SetClassLongPtrW(hwnd, GCLP_HICONSM, reinterpret_cast<LONG_PTR>(smallIcon));
    }
    if (bigIcon) {
        SendMessageW(hwnd, WM_SETICON, ICON_BIG, reinterpret_cast<LPARAM>(bigIcon));
        SetClassLongPtrW(hwnd, GCLP_HICON, reinterpret_cast<LONG_PTR>(bigIcon));
    }
}

void applyWindowsWindowChrome(GLFWwindow* window) {
    HWND hwnd = glfwGetWin32Window(window);
    if (!hwnd) {
        return;
    }

    applyWindowsWindowIcon(hwnd);

    constexpr DWORD kDwmUseImmersiveDarkMode = 20;
    constexpr DWORD kDwmUseImmersiveDarkModeLegacy = 19;
    constexpr DWORD kDwmBorderColor = 34;
    constexpr DWORD kDwmCaptionColor = 35;
    constexpr DWORD kDwmTextColor = 36;

    const BOOL useDarkCaption = TRUE;
    if (FAILED(DwmSetWindowAttribute(hwnd, kDwmUseImmersiveDarkMode, &useDarkCaption, sizeof(useDarkCaption)))) {
        DwmSetWindowAttribute(hwnd, kDwmUseImmersiveDarkModeLegacy, &useDarkCaption, sizeof(useDarkCaption));
    }

    const COLORREF captionColor = RGB(52, 53, 58);
    const COLORREF borderColor = RGB(52, 53, 58);
    const COLORREF textColor = RGB(238, 238, 242);
    DwmSetWindowAttribute(hwnd, kDwmCaptionColor, &captionColor, sizeof(captionColor));
    DwmSetWindowAttribute(hwnd, kDwmBorderColor, &borderColor, sizeof(borderColor));
    DwmSetWindowAttribute(hwnd, kDwmTextColor, &textColor, sizeof(textColor));
}
#else
void applyWindowsWindowChrome(GLFWwindow*) {
}
#endif

struct AppOptions {
    std::string cameraUrl;
};

std::string trimConfigValue(std::string value) {
    const auto isNotSpace = [](unsigned char ch) {
        return !std::isspace(ch);
    };

    value.erase(value.begin(), std::find_if(value.begin(), value.end(), isNotSpace));
    value.erase(std::find_if(value.rbegin(), value.rend(), isNotSpace).base(), value.end());
    return value;
}

std::string stripConfigComment(std::string value) {
    bool inSingleQuote = false;
    bool inDoubleQuote = false;

    for (std::size_t i = 0; i < value.size(); ++i) {
        const char ch = value[i];
        if (ch == '\'' && !inDoubleQuote) {
            inSingleQuote = !inSingleQuote;
        } else if (ch == '"' && !inSingleQuote) {
            inDoubleQuote = !inDoubleQuote;
        } else if (ch == '#' && !inSingleQuote && !inDoubleQuote) {
            value.erase(i);
            break;
        }
    }

    return value;
}

std::string unquoteConfigValue(std::string value) {
    if (value.size() >= 2) {
        const char first = value.front();
        const char last = value.back();
        if ((first == '"' && last == '"') || (first == '\'' && last == '\'')) {
            value = value.substr(1, value.size() - 2);
        }
    }
    return value;
}

bool loadConfigFile(const std::filesystem::path& path, AppOptions& options) {
    std::ifstream stream(path);
    if (!stream) {
        return false;
    }

    std::string line;
    while (std::getline(stream, line)) {
        line = trimConfigValue(stripConfigComment(line));
        if (line.empty()) {
            continue;
        }

        const std::size_t separator = line.find(':');
        if (separator == std::string::npos) {
            continue;
        }

        const std::string key = trimConfigValue(line.substr(0, separator));
        std::string value = trimConfigValue(line.substr(separator + 1));
        value = unquoteConfigValue(value);

        if (key == "camera_url" && !value.empty()) {
            options.cameraUrl = value;
        }
    }

    return true;
}

void loadDefaultConfig(AppOptions& options) {
    const std::filesystem::path configPath = std::filesystem::path{"control-panel"} / "config" / "config.yaml";
    std::error_code error;
    if (std::filesystem::is_regular_file(configPath, error) && loadConfigFile(configPath, options) && !options.cameraUrl.empty()) {
        std::cout << "Loaded camera_url from " << configPath.lexically_normal().string() << "\n";
    }
}

bool parseAppOptions(int argc, char** argv, AppOptions& options) {
    for (int i = 1; i < argc; ++i) {
        const std::string arg = argv[i];
        if (arg == "--camera-url") {
            if (i + 1 >= argc) {
                std::cout << "Missing value for --camera-url\n";
                return false;
            }
            options.cameraUrl = argv[++i];
        } else {
            std::cout << "Unknown argument: " << arg << "\n";
            return false;
        }
    }
    return true;
}

std::string formatPressureValue(double torr, std::string& unit) {
    constexpr int kSignificantFigures = 4;

    double displayValue = torr;
    unit = "Torr";

    if (torr < 1.0) {
        displayValue = torr * 1000.0;
        unit = "mTorr";
    }

    const auto decimalPlacesFor = [kSignificantFigures](double value) {
        const double magnitude = std::abs(value);
        if (magnitude <= 0.0) {
            return kSignificantFigures - 1;
        }

        const int order = static_cast<int>(std::floor(std::log10(magnitude)));
        return std::max(0, kSignificantFigures - order - 1);
    };

    int precision = decimalPlacesFor(displayValue);
    if (precision > 0) {
        const double scale = std::pow(10.0, precision);
        const double roundedValue = std::round(displayValue * scale) / scale;
        precision = decimalPlacesFor(roundedValue);
    }

    std::ostringstream out;
    out << std::fixed << std::setprecision(precision) << displayValue;
    return out.str();
}

std::string formatFixedValue(double value, int precision, double deadband) {
    const double scale = std::pow(10.0, precision);
    const double roundedDisplayValue = std::round(value * scale) / scale;
    if (std::abs(roundedDisplayValue) <= deadband) {
        value = 0.0;
    }

    std::ostringstream out;
    out << std::fixed << std::setprecision(precision) << value;
    return out.str();
}

std::string formatVoltageValue(double kilovolts) {
    return formatFixedValue(kilovolts, 2, gPressureController.config().voltagePresentThresholdKV);
}

double reportableCurrentMilliamps(double milliamps) {
    return milliamps < kCurrentReportFloorMA ? 0.0 : milliamps;
}

std::string formatCurrentValue(double milliamps) {
    return formatFixedValue(reportableCurrentMilliamps(milliamps), 3, 0.0);
}

std::filesystem::path nextSensorLogPath() {
    const std::filesystem::path logDirectory{"logs"};

    std::error_code error;
    std::filesystem::create_directories(logDirectory, error);
    if (error) {
        std::cout << "Sensor logging: could not create logs directory: " << error.message() << "\n";
    }

    for (int run = 1; run < 100000; ++run) {
        std::filesystem::path path = logDirectory / ("run_" + std::to_string(run) + ".log");
        std::filesystem::path mp4Path = path;
        std::filesystem::path aviPath = path;
        std::filesystem::path videoIndexPath = path;
        mp4Path.replace_extension(".mp4");
        aviPath.replace_extension(".avi");
        videoIndexPath.replace_extension(".video.tsv");
        error.clear();
        const bool logExists = std::filesystem::exists(path, error);
        error.clear();
        const bool mp4Exists = std::filesystem::exists(mp4Path, error);
        error.clear();
        const bool aviExists = std::filesystem::exists(aviPath, error);
        error.clear();
        const bool indexExists = std::filesystem::exists(videoIndexPath, error);
        if (!logExists && !mp4Exists && !aviExists && !indexExists) {
            return path;
        }
    }

    return logDirectory / "run_99999.log";
}

std::filesystem::path videoPathForLogPath(const std::filesystem::path& logPath, const char* extension) {
    std::filesystem::path path = logPath;
    path.replace_extension(extension);
    return path;
}

void resetVideoRecordingState() {
    gSensorLog.videoPath.clear();
    gSensorLog.videoIndexPath.clear();
    gSensorLog.lastRecordedVideoFrameId = 0;
    gSensorLog.videoWidth = 0;
    gSensorLog.videoHeight = 0;
    gSensorLog.videoFramesWritten = 0;
    gSensorLog.videoRecording = false;
    gSensorLog.videoUnavailable = false;
}

void closeVideoRecording() {
    if (gSensorLog.videoWriter.isOpened()) {
        gSensorLog.videoWriter.release();
    }
    if (gSensorLog.videoIndexStream.is_open()) {
        gSensorLog.videoIndexStream.flush();
        gSensorLog.videoIndexStream.close();
    }
    if (gSensorLog.videoRecording) {
        std::cout << "Sensor logging: video stopped " << gSensorLog.videoPath.string()
                  << " frames=" << gSensorLog.videoFramesWritten << "\n";
    }
    gSensorLog.videoRecording = false;
}
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
int main(int argc, char** argv) {
    AppOptions options{};
    loadDefaultConfig(options);
    if (!parseAppOptions(argc, argv, options)) {
        std::cout << "Usage: app [--camera-url <rtsp-url>]\n";
        return 1;
    }
    gVideoStreamEnabled = !options.cameraUrl.empty();

    if (!glfwInit()) {
        std::cout << "Failed to initialize GLFW\n";
        return 1;
    }

    glfwWindowHint(GLFW_CONTEXT_VERSION_MAJOR, 3);
    glfwWindowHint(GLFW_CONTEXT_VERSION_MINOR, 3);
    glfwWindowHint(GLFW_OPENGL_PROFILE, GLFW_OPENGL_CORE_PROFILE);

    GLFWwindow* window = glfwCreateWindow(1920, 1080, "Fusor Control Panel", nullptr, nullptr);
    if (!window) {
        std::cout << "Failed to create GLFW window\n";
        glfwTerminate();
        return 1;
    }
    applyWindowsWindowChrome(window);

    glfwMakeContextCurrent(window);
    glfwSwapInterval(1);

    if (!gladLoadGL((GLADloadfunc)glfwGetProcAddress)) {
        std::cout << "Failed to initialize GLAD\n";
        glfwDestroyWindow(window);
        glfwTerminate();
        return 1;
    }

    glfwSetFramebufferSizeCallback(window, framebufferSizeCallback);
    glfwSetMouseButtonCallback(window, mouseButtonCallback);
    glfwSetCursorPosCallback(window, cursorPositionCallback);
    glfwSetScrollCallback(window, scrollCallback);

    int framebufferWidth = 0;
    int framebufferHeight = 0;
    glfwGetFramebufferSize(window, &framebufferWidth, &framebufferHeight);
    glViewport(0, 0, framebufferWidth, framebufferHeight);

    const GLuint meshProgram = createMeshProgram();
    const GLuint lineProgram = createLineProgram();
    HudRenderer hudRenderer = createHudRenderer();
    VideoBackgroundRenderer videoBackgroundRenderer{};
    if (gVideoStreamEnabled) {
        videoBackgroundRenderer = createVideoBackgroundRenderer();
    }

    glEnable(GL_DEPTH_TEST);
    glEnable(GL_BLEND);
    glBlendFunc(GL_SRC_ALPHA, GL_ONE_MINUS_SRC_ALPHA);
    glDisable(GL_CULL_FACE);

    gCamera.reset();
    const FusorGeometry& geometry = fusorGeometry();
    GpuMesh shakerBall = buildShakerBallMesh();
    GpuMesh hvFeedthroughConductor = buildHvFeedthroughConductorMesh();
    GpuMesh hvFeedthroughExterior = buildHvFeedthroughExteriorMesh();
    GpuMesh chamberCylinder = buildCylinderMesh();
    GpuLines chamberLines = buildCylinderLines();
    PlasmaRenderer plasmaRenderer = createPlasmaRenderer(geometry);
    PressureMonitor pressureMonitor;
    MeterMonitor meterMonitor;
    ValveMonitor valveMonitor;
    VideoStream videoStream;
    pressureMonitor.start();
    meterMonitor.start();
    valveMonitor.start();
    gValveMonitor = &valveMonitor;
    gPressureController.setValveMonitor(&valveMonitor);
    if (gVideoStreamEnabled) {
        videoStream.start(options.cameraUrl);
    }

    std::cout << "OpenGL version: " << glGetString(GL_VERSION) << "\n";
    std::cout << "Left-drag to orbit, mouse wheel to zoom, F to toggle slow rotation, R to start/stop sensor logging, V to toggle camera, Esc to quit.\n";

    double previousFrameTime = glfwGetTime();
    while (!glfwWindowShouldClose(window)) {
        const double frameTime = glfwGetTime();
        const float deltaSeconds = static_cast<float>(std::clamp(frameTime - previousFrameTime, 0.0, 0.05));
        previousFrameTime = frameTime;

        const PressureSnapshot pressure = pressureMonitor.snapshot();
        const MeterSnapshot meter = meterMonitor.snapshot();
        const ValveSnapshot valve = valveMonitor.snapshot();
        VideoFrameSnapshot videoFrame;
        if (gVideoStreamEnabled) {
            videoFrame = videoStream.snapshot();
        }
        gLatestPressure = pressure;
        gLatestMeter = meter;
        if (gSensorLog.recording && !pressure.connected && !meter.connected && !videoFrame.connected) {
            stopSensorLogging();
        }
        gSensorLogControlsEnabled = pressure.connected || meter.connected || videoFrame.connected;

        const auto controlNow = std::chrono::steady_clock::now();
        const auto controlPeriod = std::chrono::milliseconds(static_cast<long long>(gPressureController.config().controlPeriodSec * 1000.0));
        if (!gControlTicked || controlNow - gLastControlTick >= controlPeriod) {
            gPressureController.tick(pressure, meter);
            gLastControlTick = controlNow;
            gControlTicked = true;
        }

        processInput(window);
        if (gAutoRotateCamera && !gCamera.dragging) {
            gCamera.yaw += kAutoOrbitRadiansPerSecond * deltaSeconds;
        }

        glfwGetFramebufferSize(window, &framebufferWidth, &framebufferHeight);
        const float aspect = framebufferHeight > 0 ? static_cast<float>(framebufferWidth) / static_cast<float>(framebufferHeight) : 1.0f;
        const Vec3 eye = gCamera.position();
        const Mat4 view = lookAt(eye, gCamera.target, {0.0f, 0.0f, 1.0f});
        const Mat4 projection = perspective(45.0f * kPi / 180.0f, aspect, 0.1f, 1000.0f);
        const Mat4 mvp = multiply(projection, view);
        recordVideoFrameIfNeeded(videoFrame);
        logSensorsIfNeeded(pressure, meter);

        glClearColor(0.055f, 0.06f, 0.078f, 1.0f);
        glClear(GL_COLOR_BUFFER_BIT | GL_DEPTH_BUFFER_BIT);

        bool cameraFrameVisible = false;
        bool cameraConnected = false;
        if (gVideoStreamEnabled) {
            cameraConnected = videoFrame.connected;
            if (gVideoBackgroundVisible && videoFrame.hasFrame) {
                const double frameAge = std::chrono::duration<double>(std::chrono::steady_clock::now() - videoFrame.receivedAt).count();
                if (frameAge <= kVideoLastFrameHoldSeconds) {
                    updateVideoBackgroundTexture(videoBackgroundRenderer, videoFrame);
                    drawVideoBackground(videoBackgroundRenderer, framebufferWidth, framebufferHeight);
                    cameraFrameVisible = true;
                }
            }
        }

        if (!cameraFrameVisible) {
            drawMesh(meshProgram, shakerBall, mvp, eye, 0.58f, 0.60f, 0.62f, 1.0f);
            drawMesh(meshProgram, hvFeedthroughConductor, mvp, eye, 0.58f, 0.60f, 0.62f, 1.0f);

            drawPlasma(
                plasmaRenderer,
                mvp,
                eye,
                makePlasmaParams(geometry, static_cast<float>(frameTime))
            );

            glDepthMask(GL_FALSE);
            drawMesh(meshProgram, chamberCylinder, mvp, eye, 0.28f, 0.68f, 0.95f, 0.17f);
            drawMesh(meshProgram, hvFeedthroughExterior, mvp, eye, 0.28f, 0.68f, 0.95f, 0.17f);
            drawLines(lineProgram, chamberLines, mvp, 0.45f, 0.85f, 1.0f, 0.46f, 1.25f);
            glDepthMask(GL_TRUE);
        }

        SensorHudData hudData{};
        hudData.pressure = makePressureHudData(pressure);
        hudData.voltage = makeVoltageHudData(meter);
        hudData.current = makeCurrentHudData(meter);
        hudData.cameraConnected = cameraConnected;
        hudData.recording = gSensorLog.recording;
        hudData.loggingAvailable = gSensorLogControlsEnabled;
        const double toastAge = frameTime - gLogSavedToastStartedAt;
        if (toastAge >= 0.0 && toastAge < kLogSavedToastHoldSeconds + kLogSavedToastFadeSeconds) {
            const double fadeAge = std::max(0.0, toastAge - kLogSavedToastHoldSeconds);
            hudData.logSavedAlpha = static_cast<float>(1.0 - fadeAge / kLogSavedToastFadeSeconds);
            const double liftT = std::clamp(toastAge / 0.35, 0.0, 1.0);
            hudData.logSavedLift = static_cast<float>(8.0 * (1.0 - (1.0 - liftT) * (1.0 - liftT)));
        }
        gSensorHudLayout = drawSensorHud(hudRenderer, framebufferWidth, framebufferHeight, hudData);

        ControlHudData controlHudData = buildControlHudData(gPressureController.snapshot());
        applyValveSnapshotToHud(controlHudData, valve);
        gControlHudLayout = drawControlHud(hudRenderer, framebufferWidth, framebufferHeight, gSensorHudLayout.panel, controlHudData);

        glfwSwapBuffers(window);
        glfwPollEvents();
    }

    glfwHideWindow(window);
    gPressureController.setValveMonitor(nullptr);
    gValveMonitor = nullptr;
    videoStream.requestStop();
    meterMonitor.requestStop();
    pressureMonitor.requestStop();
    valveMonitor.requestStop();

    stopSensorLogging();

    const auto shutdownDeadline = std::chrono::steady_clock::now() + kShutdownGracePeriod;
    while (std::chrono::steady_clock::now() < shutdownDeadline
           && (videoStream.running() || meterMonitor.running() || pressureMonitor.running() || valveMonitor.running())) {
        std::this_thread::sleep_for(std::chrono::milliseconds(25));
    }
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

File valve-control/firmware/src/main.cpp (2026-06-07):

#include <Arduino.h>
#include <NimBLEDevice.h>
#include <Preferences.h>

constexpr int stepPin = D0;
constexpr int dirPin = D1;
constexpr int enablePin = D2;

constexpr bool enableActiveLow = false;
constexpr bool invertDirection = true;
constexpr int stepPulseUs = 700;
constexpr int stepGapUs = 700;

constexpr long closedLimitSteps = 0;
constexpr int defaultJogSteps = 40;

constexpr const char* deviceName = "Fusor-Valve";
constexpr const char* serviceUuid = "9b3f2001-7f64-4f76-8f6d-8a2f0b6a4c10";
constexpr const char* statusUuid = "9b3f2002-7f64-4f76-8f6d-8a2f0b6a4c10";
constexpr const char* commandUuid = "9b3f2003-7f64-4f76-8f6d-8a2f0b6a4c10";
constexpr uint32_t heartbeatIntervalMs = 1000;

enum ValveMode : uint8_t {
  MODE_CALIBRATE = 0,
  MODE_RUN = 1,
};

Preferences prefs;

long positionSteps = 0;
long openLimitSteps = 0;
ValveMode currentMode = MODE_CALIBRATE;
int jogSteps = defaultJogSteps;

NimBLECharacteristic* statusChar = nullptr;
bool clientConnected = false;
unsigned long lastStatusSentMs = 0;

const char* modeName(ValveMode m) {
  return m == MODE_RUN ? "RUN" : "CALIBRATE";
}

void setDriverEnabled(bool enabled) {
  digitalWrite(enablePin, enableActiveLow ? !enabled : enabled);
}

void savePosition() {
  prefs.putLong("pos", positionSteps);
}

void saveOpenLimit() {
  prefs.putLong("open", openLimitSteps);
}

void saveMode() {
  prefs.putUChar("mode", static_cast<uint8_t>(currentMode));
}

void printStatus() {
  Serial.printf("mode=%s pos=%ld open=%ld jog=%d\n",
                modeName(currentMode), positionSteps, openLimitSteps, jogSteps);
}

void sendStatus() {
  if (!statusChar) {
    return;
  }
  char buffer[96];
  snprintf(buffer, sizeof(buffer),
           "pos=%ld,open=%ld,mode=%s",
           positionSteps, openLimitSteps, modeName(currentMode));
  statusChar->setValue(buffer);
  if (clientConnected) {
    statusChar->notify();
  }
  lastStatusSentMs = millis();
}

long clampTarget(long target) {
  if (currentMode == MODE_CALIBRATE) {
    return target;
  }
  if (target < closedLimitSteps) {
    return closedLimitSteps;
  }
  if (openLimitSteps > 0 && target > openLimitSteps) {
    return openLimitSteps;
  }
  return target;
}

void moveTo(long target) {
  target = clampTarget(target);
  long delta = target - positionSteps;

  if (delta == 0) {
    printStatus();
    sendStatus();
    return;
  }

  bool openDirection = delta > 0;
  long steps = labs(delta);
  bool dirHigh = openDirection != invertDirection;

  setDriverEnabled(true);
  digitalWrite(dirPin, dirHigh ? HIGH : LOW);
  delayMicroseconds(20);

  for (long i = 0; i < steps; i++) {
    digitalWrite(stepPin, LOW);
    delayMicroseconds(stepPulseUs);
    digitalWrite(stepPin, HIGH);
    delayMicroseconds(stepGapUs);
  }
  setDriverEnabled(false);

  positionSteps = target;
  savePosition();
  printStatus();
  sendStatus();
}

void jog(bool openDirection) {
  long target = positionSteps + (openDirection ? jogSteps : -jogSteps);
  moveTo(target);
}

void setMode(ValveMode mode) {
  currentMode = mode;
  saveMode();
  if (mode == MODE_RUN) {
    long clamped = clampTarget(positionSteps);
    if (clamped != positionSteps) {
      positionSteps = clamped;
      savePosition();
    }
  }
  Serial.printf("mode -> %s\n", modeName(currentMode));
}

void printBanner() {
  Serial.println();
  Serial.println("==========================================");
  Serial.println("           FUSOR VALVE");
  Serial.println("==========================================");
  Serial.printf("  mode = %s\n", modeName(currentMode));
  Serial.printf("  pos  = %ld\n", positionSteps);
  Serial.printf("  open = %ld\n", openLimitSteps);
  Serial.printf("  BLE  = %s\n", deviceName);
  Serial.println("==========================================");
  if (openLimitSteps <= 0) {
    Serial.println("  No open limit yet. In CALIBRATE mode, jog to the");
    Serial.println("  mechanical open position and press 'm' (or use");
    Serial.println("  ':SETOPEN <n>' if you know the value).");
  }
  if (positionSteps == 0 && openLimitSteps > 0) {
    Serial.println("  NOTE: pos = 0. If the valve is NOT physically at the");
    Serial.println("  closed reference, correct it with ':SETPOS <n>'");
    Serial.println("  before switching to RUN mode.");
  }
  Serial.println();
}

void printHelp() {
  Serial.println("Single-char commands:");
  Serial.println("  a / left arrow   = jog closed");
  Serial.println("  d / right arrow  = jog open");
  Serial.println("  c                = go to closed (0)");
  Serial.println("  o                = go to open limit");
  Serial.println("  p                = print status");
  Serial.println("  z                = set current position as zero");
  Serial.println("  m                = mark current position as open limit");
  Serial.println("  [ / ]            = smaller / bigger jog");
  Serial.println("  ?                = help");
  Serial.println();
  Serial.println("Text commands (type ':' then command + Enter):");
  Serial.println("  :MODE CALIBRATE | :MODE RUN");
  Serial.println("  :SETOPEN <n>     restore open limit (calibration value)");
  Serial.println("  :SETPOS <n>      assert current position");
  Serial.println("  :MOVETO <n>      move to absolute step");
  Serial.println("  :MOVE <d>        move by delta steps");
  Serial.println("  :CLOSE | :OPEN | :STATUS");
  Serial.println();
}

void handleChar(char c) {
  if (c == 'a' || c == 'A') {
    jog(false);
  } else if (c == 'd' || c == 'D') {
    jog(true);
  } else if (c == 'c' || c == 'C') {
    moveTo(closedLimitSteps);
  } else if (c == 'o' || c == 'O') {
    if (openLimitSteps > 0) {
      moveTo(openLimitSteps);
    } else {
      Serial.println("open limit not set");
    }
  } else if (c == 'p' || c == 'P') {
    printStatus();
    sendStatus();
  } else if (c == 'z' || c == 'Z') {
    positionSteps = 0;
    savePosition();
    Serial.println("zeroed");
    sendStatus();
  } else if (c == 'm' || c == 'M') {
    openLimitSteps = positionSteps;
    saveOpenLimit();
    Serial.println("open limit marked");
    sendStatus();
  } else if (c == '[') {
    jogSteps = max(1, jogSteps / 2);
    printStatus();
  } else if (c == ']') {
    jogSteps = min(3200, jogSteps * 2);
    printStatus();
  } else if (c == '?') {
    printHelp();
  }
}

bool startsWith(const String& s, const char* prefix) {
  return s.startsWith(prefix);
}
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
